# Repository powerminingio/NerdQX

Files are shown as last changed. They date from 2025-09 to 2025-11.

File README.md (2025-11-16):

NerdQX
<sup>Revision 1.0</sup>

> The standard and spearhead of current multi-ASIC home miners based on open hardware.

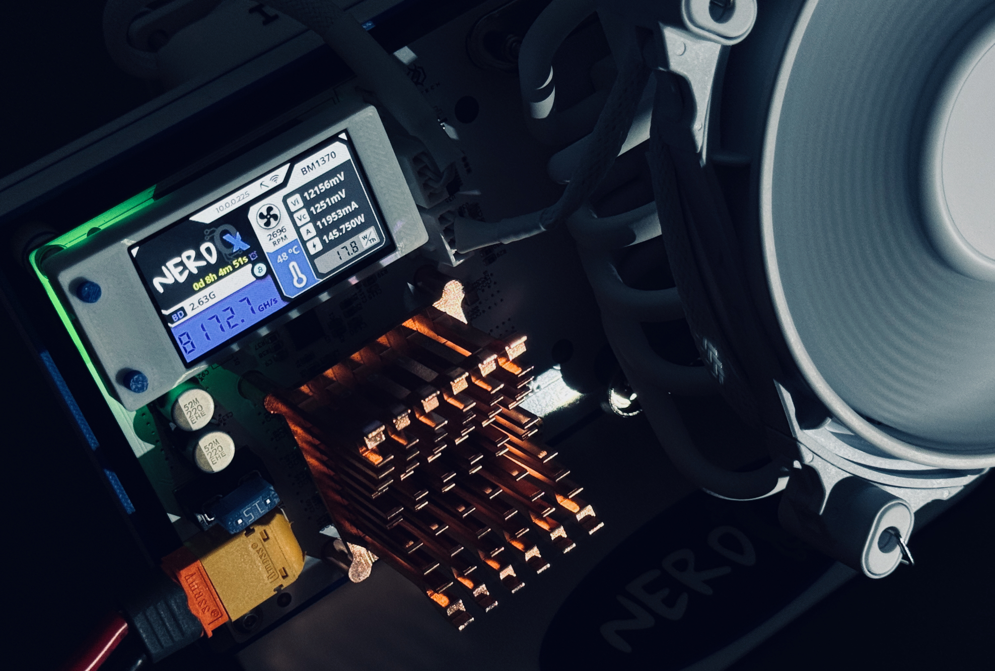
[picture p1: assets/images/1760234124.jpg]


## About

**NerdQX** is a new development based on [NerdQaxe++](https://github.com/shufps/qaxe). NerdQX also has four BM1370 ASIC
chips, a different PCB geometry, and significantly improved and simplified safety mechanisms. 

The NerdQX was developed as the world's first multi-ASIC home miner for overclocking, which also enables extremely 
efficient mining. Furthermore, the NerdQX can measure the temperature of all four ASICs separately and directly, in 
addition to the existing and somewhat less accurate variant. 

NerdQX offers full compatibility with the [ESP Miner NerdQAxe+](https://github.com/shufps/ESP-Miner-NerdQAxePlus) 
firmware, which has been specially enhanced for the NerdQX. This means you get the benefits of ongoing support and 
further development on an open source basis. 

Many small and large improvements make the NerdQX the new standard for multi-ASIC home miners based on open hardware.

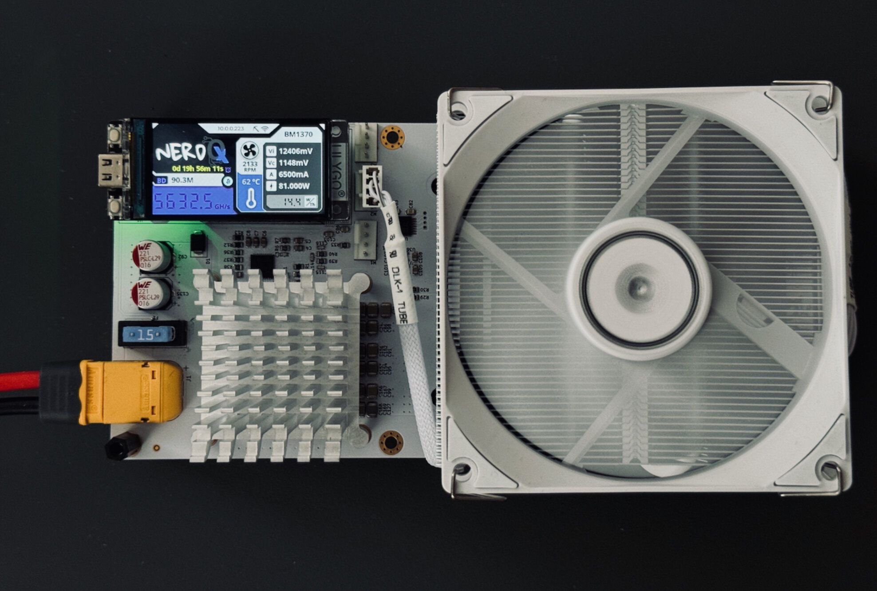
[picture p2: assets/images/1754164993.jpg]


## Highlights

### Four ASIC BM1370 processors with clock speeds up to 1000 MHz
> Unique in open-source home mining worldwide – ready for performance or economy mode.

### New PCB design with significantly increased copper and optimized conductor tracks
> The entire layout of the NerdQX has been redesigned electrically and thermally. The use of a significantly higher 
  copper ratio in the conductor tracks significantly improves the current carrying capacity of the board – even 
  under permanently high ASIC loads. The wider spacing and targeted routing ensure stable power supply, reduced heat 
  loss, and more even temperature distribution, while at the same time greatly improving efficiency.

### Dedicated cooling of the VREGs with custom-made heat sinks
> Unlike previous DIY miners, where voltage regulators often remain completely uncooled, NerdQX sets a new standard 
  here: The VREGs have been mechanically offset to enable the best possible airflow and heat dissipation. 
  In combination with a customized, thermally adapted heat sink, the resulting power loss is efficiently dissipated – 
  a concept that has previously only been used in industrial mining rigs. This measure not only extends the service 
  life of the components, but also allows safe overclocking without the risk of thermal instability in the power range 
  for the first time.
  
> **NOTE:** This heatsink is available from [Ix Tech](https://ixtech.xyz) not DigiKey.

### XT60 power connector
> Industry standard: extremely low contact resistance, high current carrying capacity, and reliable contact - even 
  in mobile or vibration-prone setups.

### Mini automotive fuse, set to the NerdQX power rating of 15 amps
> Robust, cost-effective, and easy to replace – provides additional protection against short circuits or overcurrent 
  without the need for complicated safety mechanisms, while allowing for simple visual checks of functionality.

### 4-pin PWM connector for up to three fans or AiO cooling
> Modular, efficient, prepared for quiet or aggressive cooling strategies.

### Rounded PCB corners for better protection and a high-quality overall impression
> A detail that makes safety and manufacturing quality visible.

### Proprietary open-source firmware
> The NerdQX firmware is based on the established open source NerdQaxe++ firmware, but has been specifically 
  enhanced for the new design and architecture of the NerdQX. These adjustments allow the NerdQX to be precisely 
  controlled in the range from underclocking to high-performance operation without compromising security or 
  transparency.

### Significantly improved sensor technology for temperature monitoring of all four ASICs
> Precise temperature measurement allows perfect control over thermal development during cooling. In addition to the 
  not entirely accurate temperature measurement of the ASIC, the NerdQX allows direct measurement and output of the 
  current temperature per ASIC processor for the first time.

## Collaboration

The NerdQX project was developed by an international team of enthusiasts. 

| Ix Tech | PlebBase | phil31 | shufps |
|---|---|---|---|
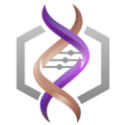
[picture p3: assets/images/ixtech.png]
Ix Tech (https://ixtech.xyz)
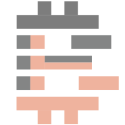
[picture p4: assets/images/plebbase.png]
PlebBase (https://plebbase.com)
|   |  | (https://github.com/phil31) | (https://github.com/shufps) |
| (https://x.com/IxTechCrypto) | (https://x.com/trendkraft) | | (https://x.com/Pmaxsd) |
 
> Special thanks go to shufps, who developed the NerdQaxe and the corresponding firmware; without him, much of this would
  not have been possible. Thanks also go to the many other talented developers who have been involved in the Nerd* 
  projects so far.

## Development

The further development of the NerdQX is being actively pursued in order to develop additional ideas and features with
the goal of creating the perfect multi-ASIC home miner that sets new standards.

## Table of Content

* [NerdQX original sources](assets/ORIGINAL_SOURCES.md)
* [NerdQX review on PlebBase](https://plebbase.com/development/all-eyez-nerdqx)
* [Official firmware](https://github.com/shufps/ESP-Miner-NerdQAxePlus)
* [Changelog](assets/CHANGELOG.md) of the project.

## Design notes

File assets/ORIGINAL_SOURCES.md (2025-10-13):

# 🛡️ NerdQX ORIGINAL

NerdQX Logo

The **NerdQX project** was created by an international team of enthusiasts and is released as an **open-source initiative**.

## Collaboration 🤝

- The project may only be built and distributed under **open-source principles**.
- Any distribution or resale must always link back to the **official source repository**.
- Unauthorized or closed-source derivatives are not permitted.
- If you would like to be listed as an original source or reseller, please **[contact the project team](https://plebbase.com/nerdqx-core-team) directly**.

We kindly encourage new manufacturers or sellers to also **support the team’s ongoing efforts**. The development of 
NerdQX has required significant time and resources, and the project continues to be actively maintained and improved.
Voluntary contributions or forms of appreciation help ensure that the developers can continue to build and enhance the 
project — and any support provided will be shared directly among the core team members.

---

## Important Notice ⚠️
This is the **only official list** of legitimate sources for the NerdQX.
- Only the links listed here are **trusted and verified**.
- Any other websites, shops, or offers are **not authorized**.
- Similarly, shops that are not on this list **do not support** the project and pose an ethical problem.
- The core team does **not provide** support for non-ORIGINAL NerdQX.

👉 Always purchase through the original sources listed below.

---

## Original sources

| Provider / Shop | Website | Region | Shipping | Contact |
|---|---|---|---|---|
| **Ix Tech** | [ixtech.xyz](https://ixtech.xyz/) | USA  | Worldwide | support@ixtech.xyz |

---

© 2025 NerdQX Project.

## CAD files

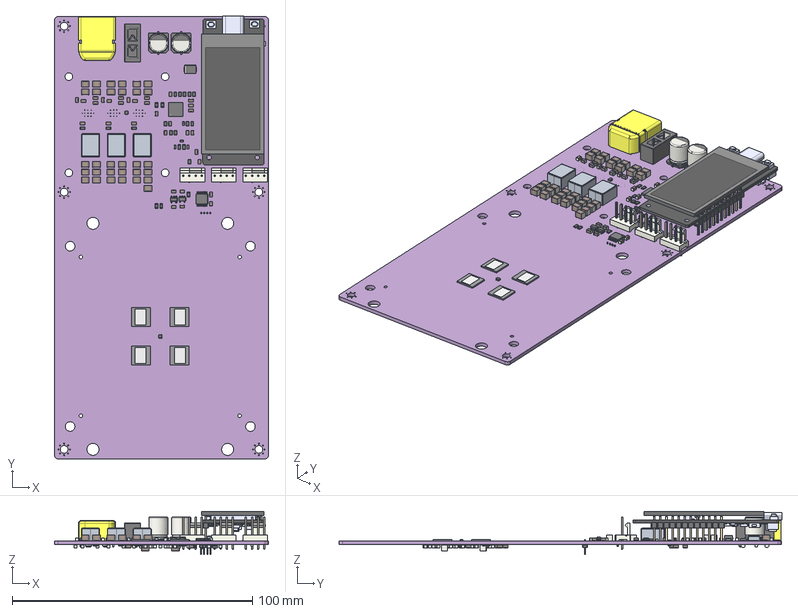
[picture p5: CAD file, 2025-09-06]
assets/3d model/NerdQX.step
89.0 x 184.2 x 17.9 mm
C_1210_3225Metric x 36
R_0805_2012Metric x 43
C_0805_2012Metric x 100
SOT-563 x 2
11150900A x 6
53134900A x 3
Label for FP1006V2-R x 3
CP_Elec_8x10 x 2
C_0603_1608Metric x 4
QFN-40-1EP_6x6mm_P0.5mm
FanPinHeader_1x04_P2.54mm_Vertical x 3
MainBoard_3D
Ecran
1_Male_Pin_2.54_mm x 24
D_SMB
TSSOP-14_4.4x5mm_P0.65mm
SOT-23-5 x 2
Fuseholder_Blade_Mini_Keystone_3568
D_SOD-128
XT60PW-M--3DModel-STEP-269445
SOT-23-6
NerdQX 1.88.1
VSSOP-8_2.3x2mm_P0.5mm
MSOP-10_3x3mm_P0.5mm
D_SOD-123
PinHeader_1x04_P1.27mm_Vertical
WSON-8-1EP_2x2mm_P0.5mm_EP0.9x1.6mm
Nerd QX_PCB

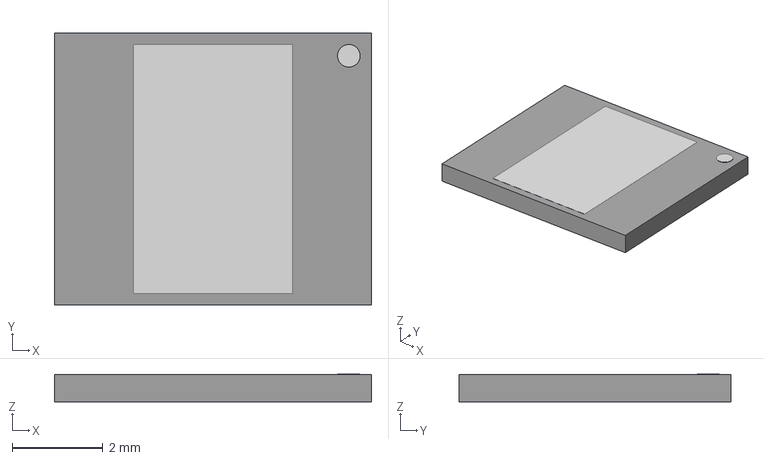
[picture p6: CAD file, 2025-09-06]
scheme/3d/bm1366.step
7.00 x 6.00 x 0.61 mm

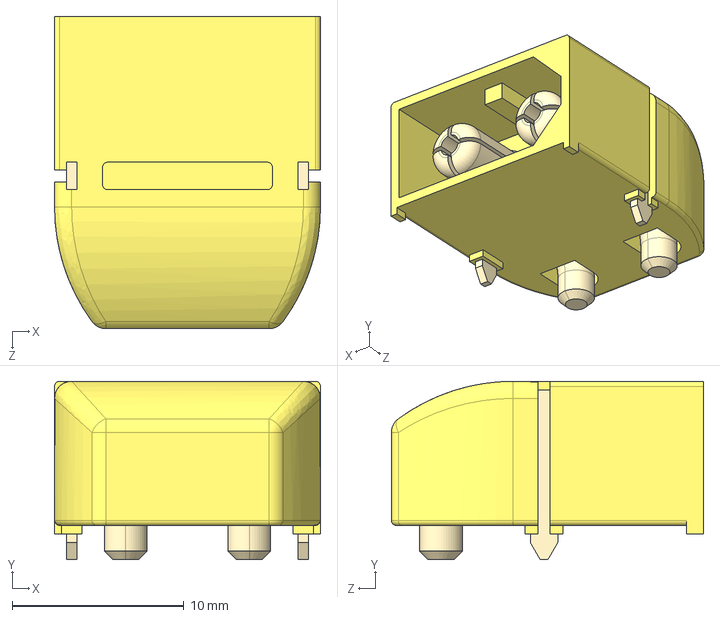
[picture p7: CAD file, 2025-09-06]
scheme/3d/XT60PW MALE.STEP
15.5 x 10.4 x 18.2 mm

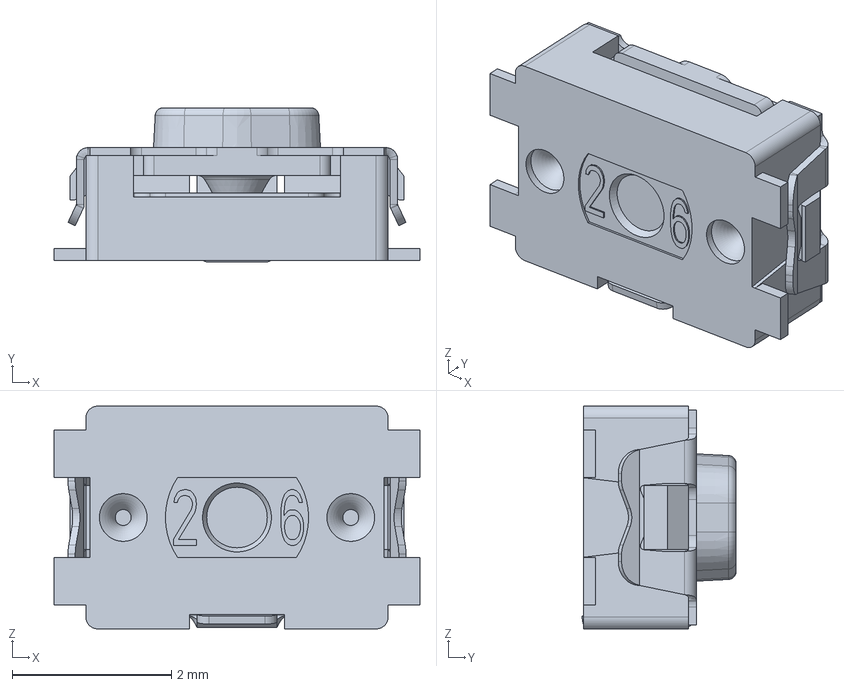
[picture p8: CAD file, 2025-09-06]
scheme/3d/KMR231GLFS.stp
4.60 x 1.94 x 2.80 mm

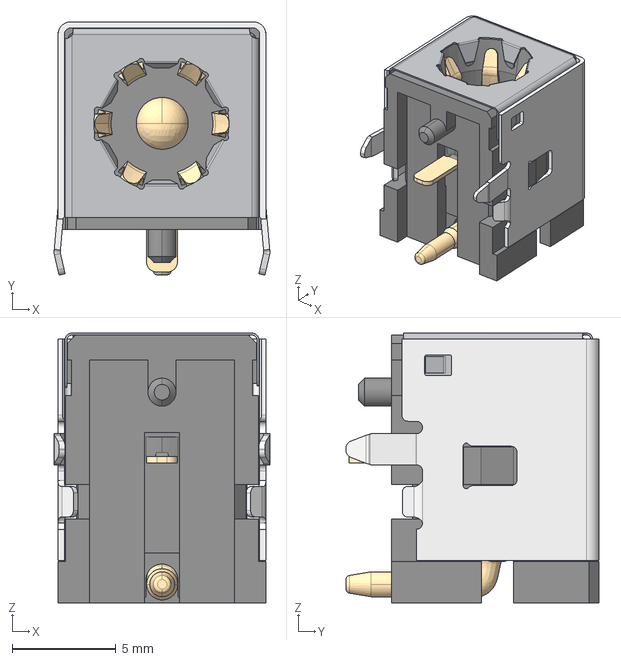
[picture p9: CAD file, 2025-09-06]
scheme/3d/DCJ250-20-B-XX-X_REVA1.step
10.4 x 12.2 x 13.0 mm

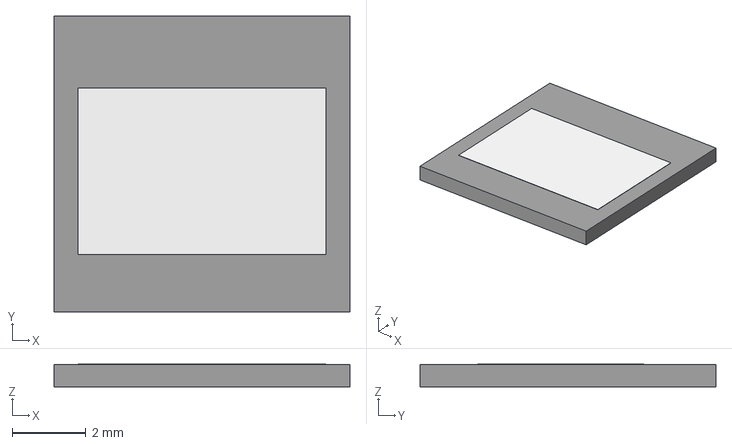
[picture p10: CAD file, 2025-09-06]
scheme/3d/bm1370.step
8.00 x 8.00 x 0.61 mm

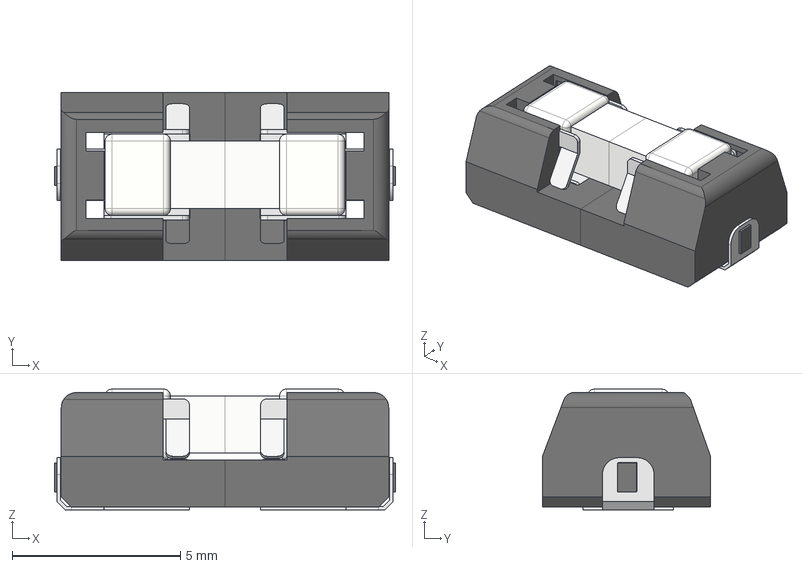
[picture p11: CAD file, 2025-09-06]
scheme/3d/Littelfuse 0154.500DRT without value_black v2.step
10.1 x 5.00 x 3.59 mm
Komponente1
Komponente2
Komponente3
Komponente4

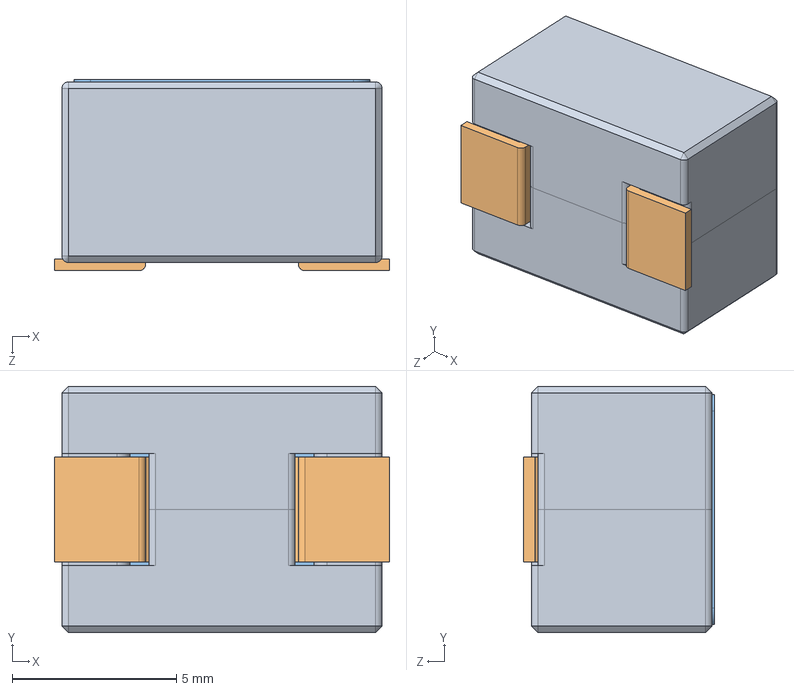
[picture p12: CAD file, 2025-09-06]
scheme/3d/FP1006V2-R.STEP
10.2 x 7.50 x 5.83 mm
11150900A x 2
53134900A
Label for FP1006V2-R

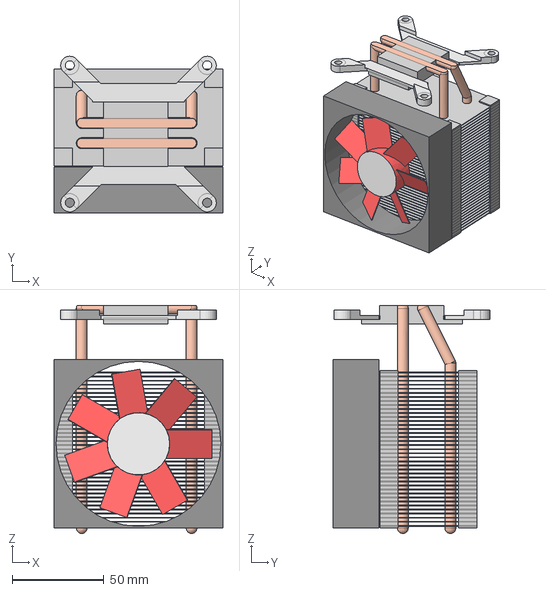
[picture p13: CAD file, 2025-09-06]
scheme/3d/lga115x.step
92.0 x 85.5 x 124.5 mm

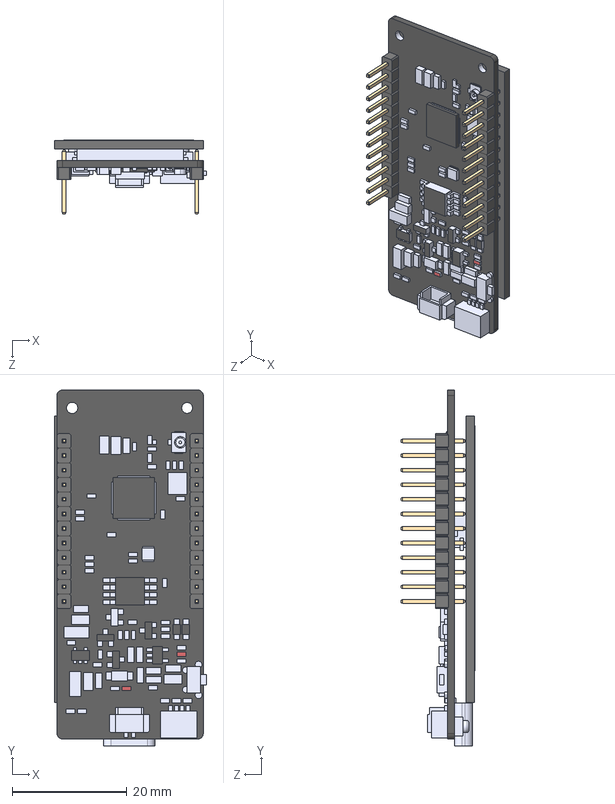
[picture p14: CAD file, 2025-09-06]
scheme/3d/T-Display-S3.STEP
26.5 x 62.0 x 12.9 mm
MainBoard_3D
Ecran
1_Male_Pin_2.54_mm x 24

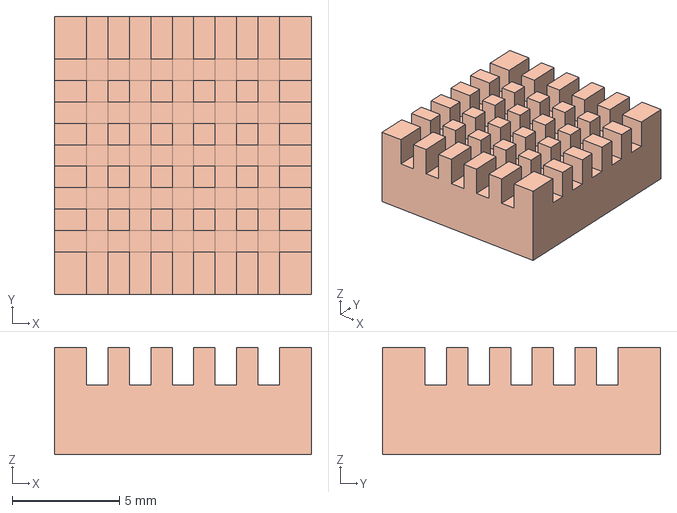
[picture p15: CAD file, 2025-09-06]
scheme/3d/heatsink-13x12x5.step
12.0 x 13.0 x 5.00 mm

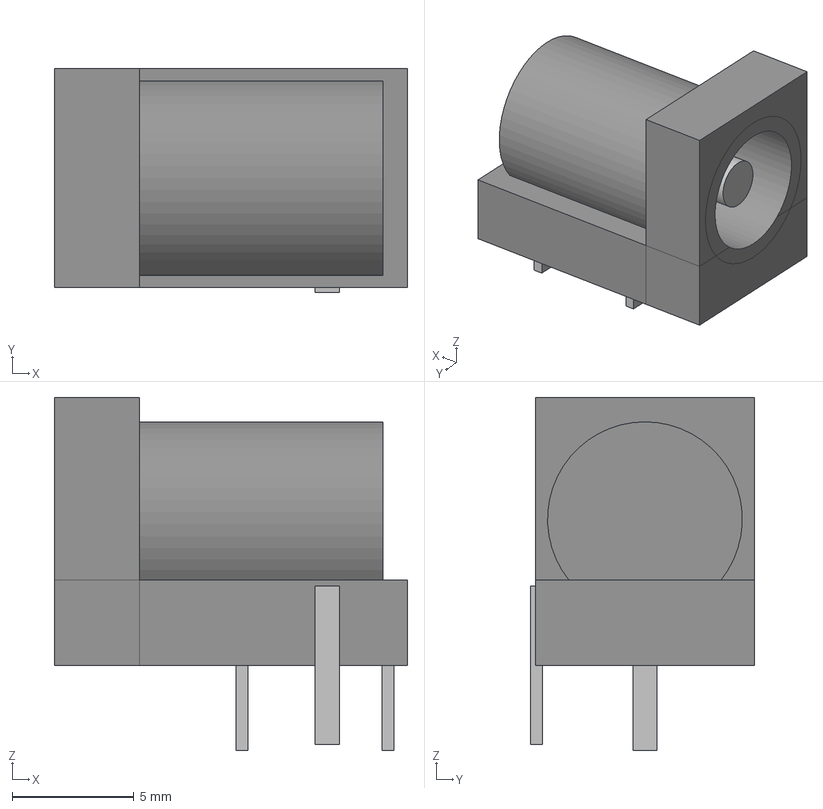
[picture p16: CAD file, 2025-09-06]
scheme/3d/barrel-jack.step
14.5 x 9.20 x 14.5 mm

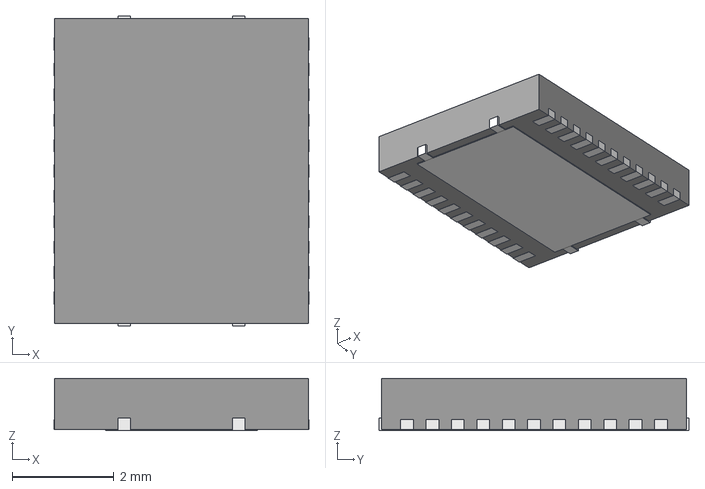
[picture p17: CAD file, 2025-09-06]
scheme/3d/csg95472.step
5.02 x 6.10 x 1.02 mm

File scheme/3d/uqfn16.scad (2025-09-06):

color("#505050") cube([1.8,2.6,0.5]);

translate([0.15, 2.6/2, 0.13/2-0.01]) {
    for (i=[-0.6:0.4:0.6]) {
        translate([0, i,0]) color("lightgray") cube([0.4,0.2,0.13], center=true);
    }
}

translate([0.15+1.5, 2.6/2, 0.13/2-0.01]) {
    for (i=[-0.6:0.4:0.6]) {
        translate([0, i,0]) color("lightgray") cube([0.4,0.2,0.13], center=true);
    }
}


translate([1.8/2,0.16, 0.13/2-0.01]) {
    for (i=[-0.6:0.4:0.6]) {
        translate([i, 0,0]) color("lightgray") cube([0.2,0.4,0.13], center=true);
    }
}

translate([1.8/2,2.45, 0.13/2-0.01]) {
    for (i=[-0.6:0.4:0.6]) {
        translate([i, 0,0]) color("lightgray") cube([0.2,0.4,0.13], center=true);
    }
}

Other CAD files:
scheme/3d/bm1370.scad
scheme/3d/csd95472.scad

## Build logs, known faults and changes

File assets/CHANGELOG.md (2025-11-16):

# Changelog for NerdQX project
## Revisions

### 1.0.1
* Capacitors increased to a higher nF rated power
* Updated schematics with correct cap rating
* Gerber list re-exported and verified
* Pick & Place list/configuration exported and verified
* BOM updated according to current schematics

### 1.0
* Horizontal PCB geometry and alignment
* New alignment of voltage regulators
* XT60 power connection
* Increase in trace spacing compliance
* Add fiducials for both sides
* Mounting holes for custom VREG coolers implemented
* Add I2C pull-up
* Temperature diode positioned centrally between ASIC processors
* Tmux implemented for direct ASIC measurement
* Additional 4-pin for fan implemented (M3)
* Blade-type fuse holder supporting up to 30A mini automotive fuse
* Round corners of PCB

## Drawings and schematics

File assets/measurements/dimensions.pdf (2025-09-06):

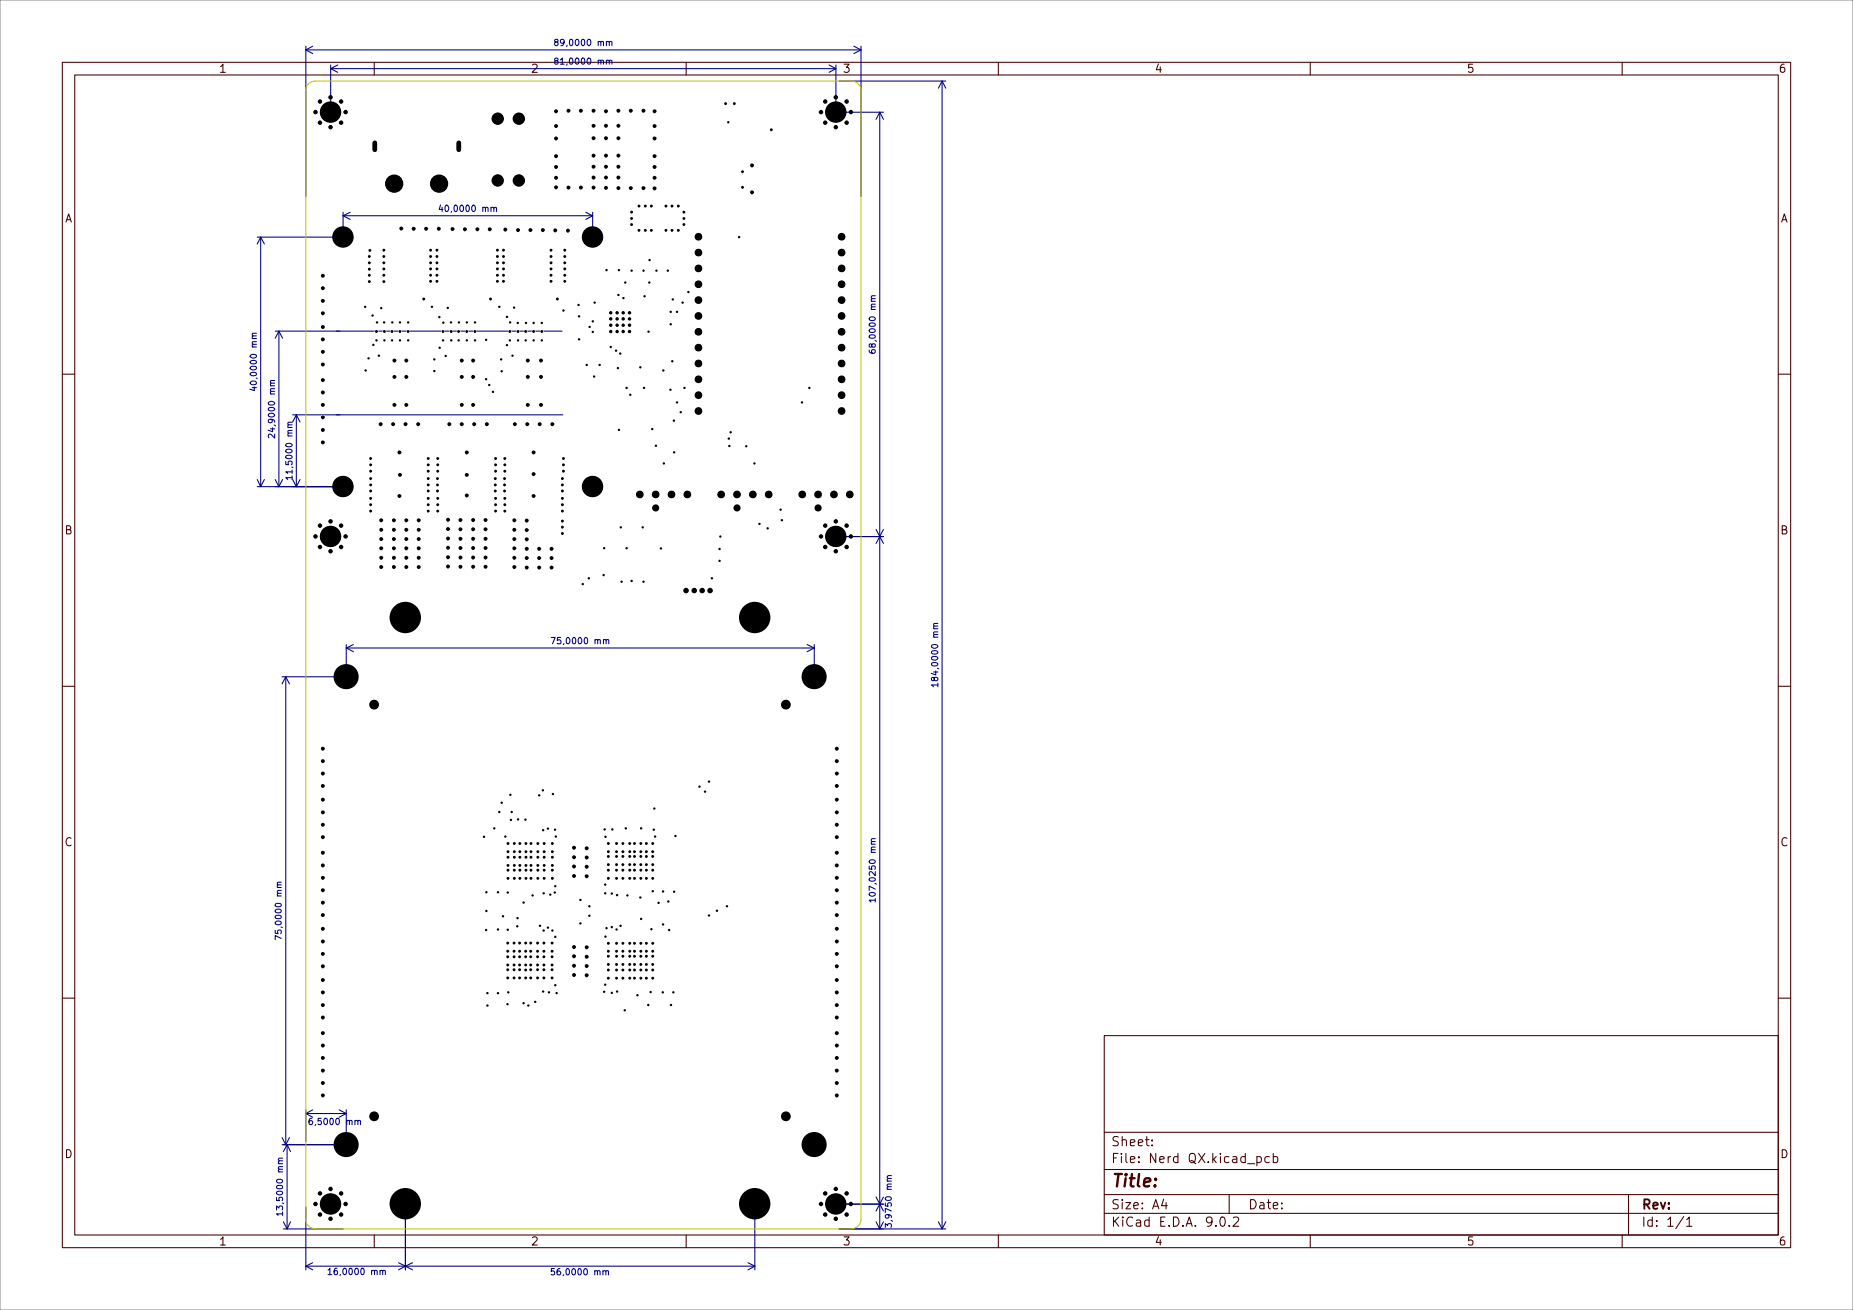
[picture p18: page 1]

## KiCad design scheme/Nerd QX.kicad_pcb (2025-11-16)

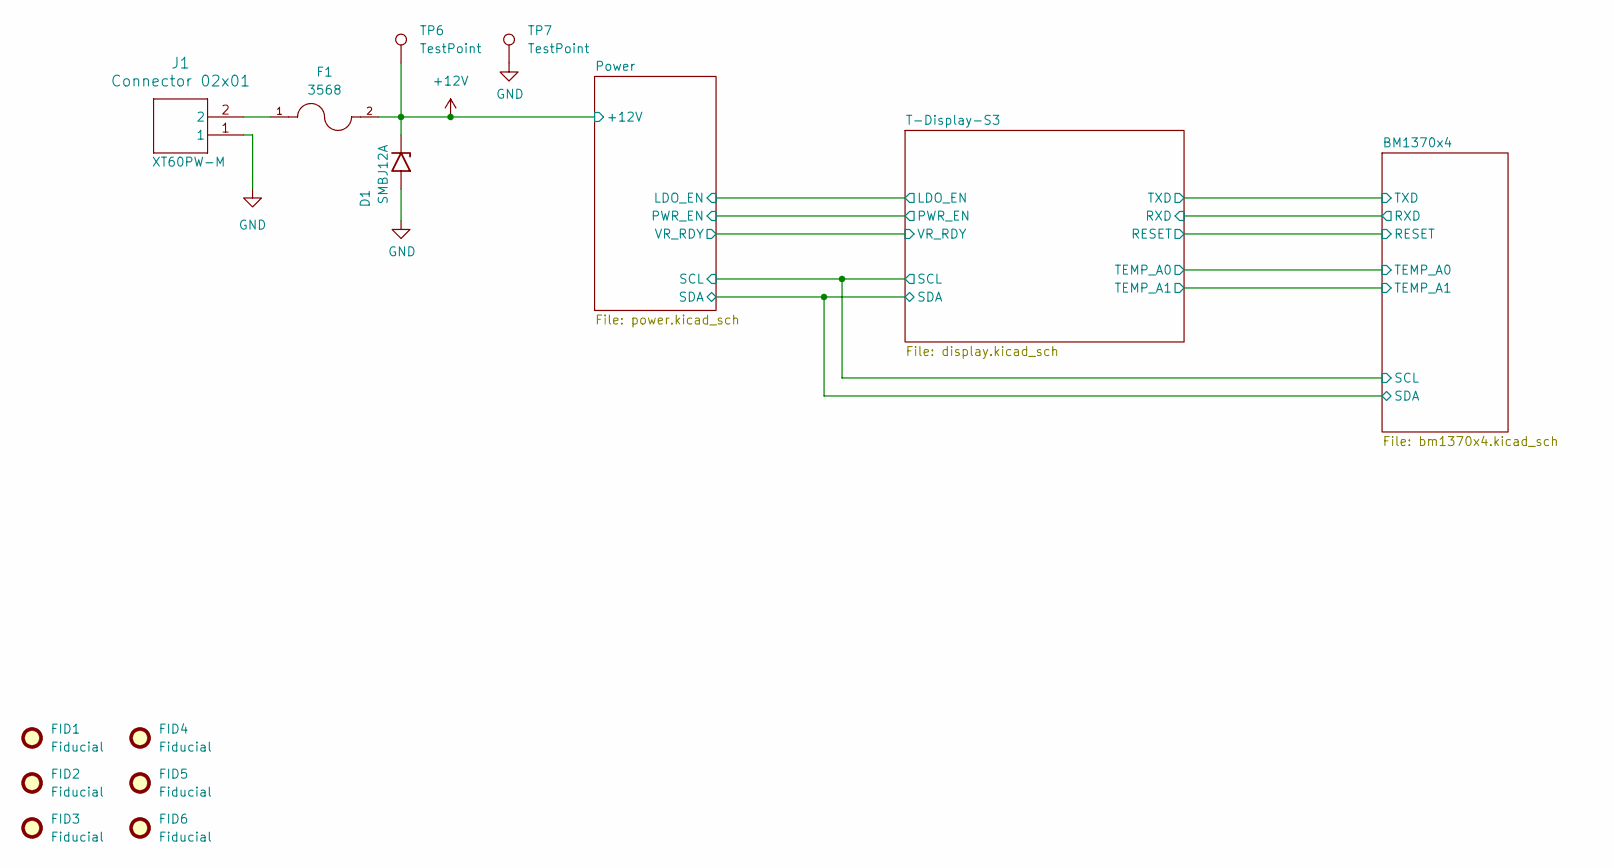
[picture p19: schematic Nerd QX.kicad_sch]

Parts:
D1: SMBJ12A; D_SMB
F1: 3568; Fuseholder_Blade_Mini_Keystone_3568
FID1, FID2, FID3, FID4, FID5, FID6: Fiducial; Fiducial_1mm_Mask3mm
J1: Connector 02x01; AMASS_XT60PW-M_1x02_P7.20mm_Horizontal
TP6, TP7: TestPoint; TestPoint_Pad_D2.0mm

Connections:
+12V: D1.1 (A1), F1.2, TP6.1; also elsewhere on the board
GND: D1.2 (A2), J1.1, TP7.1; also elsewhere on the board
unnamed: F1.1, J1.2

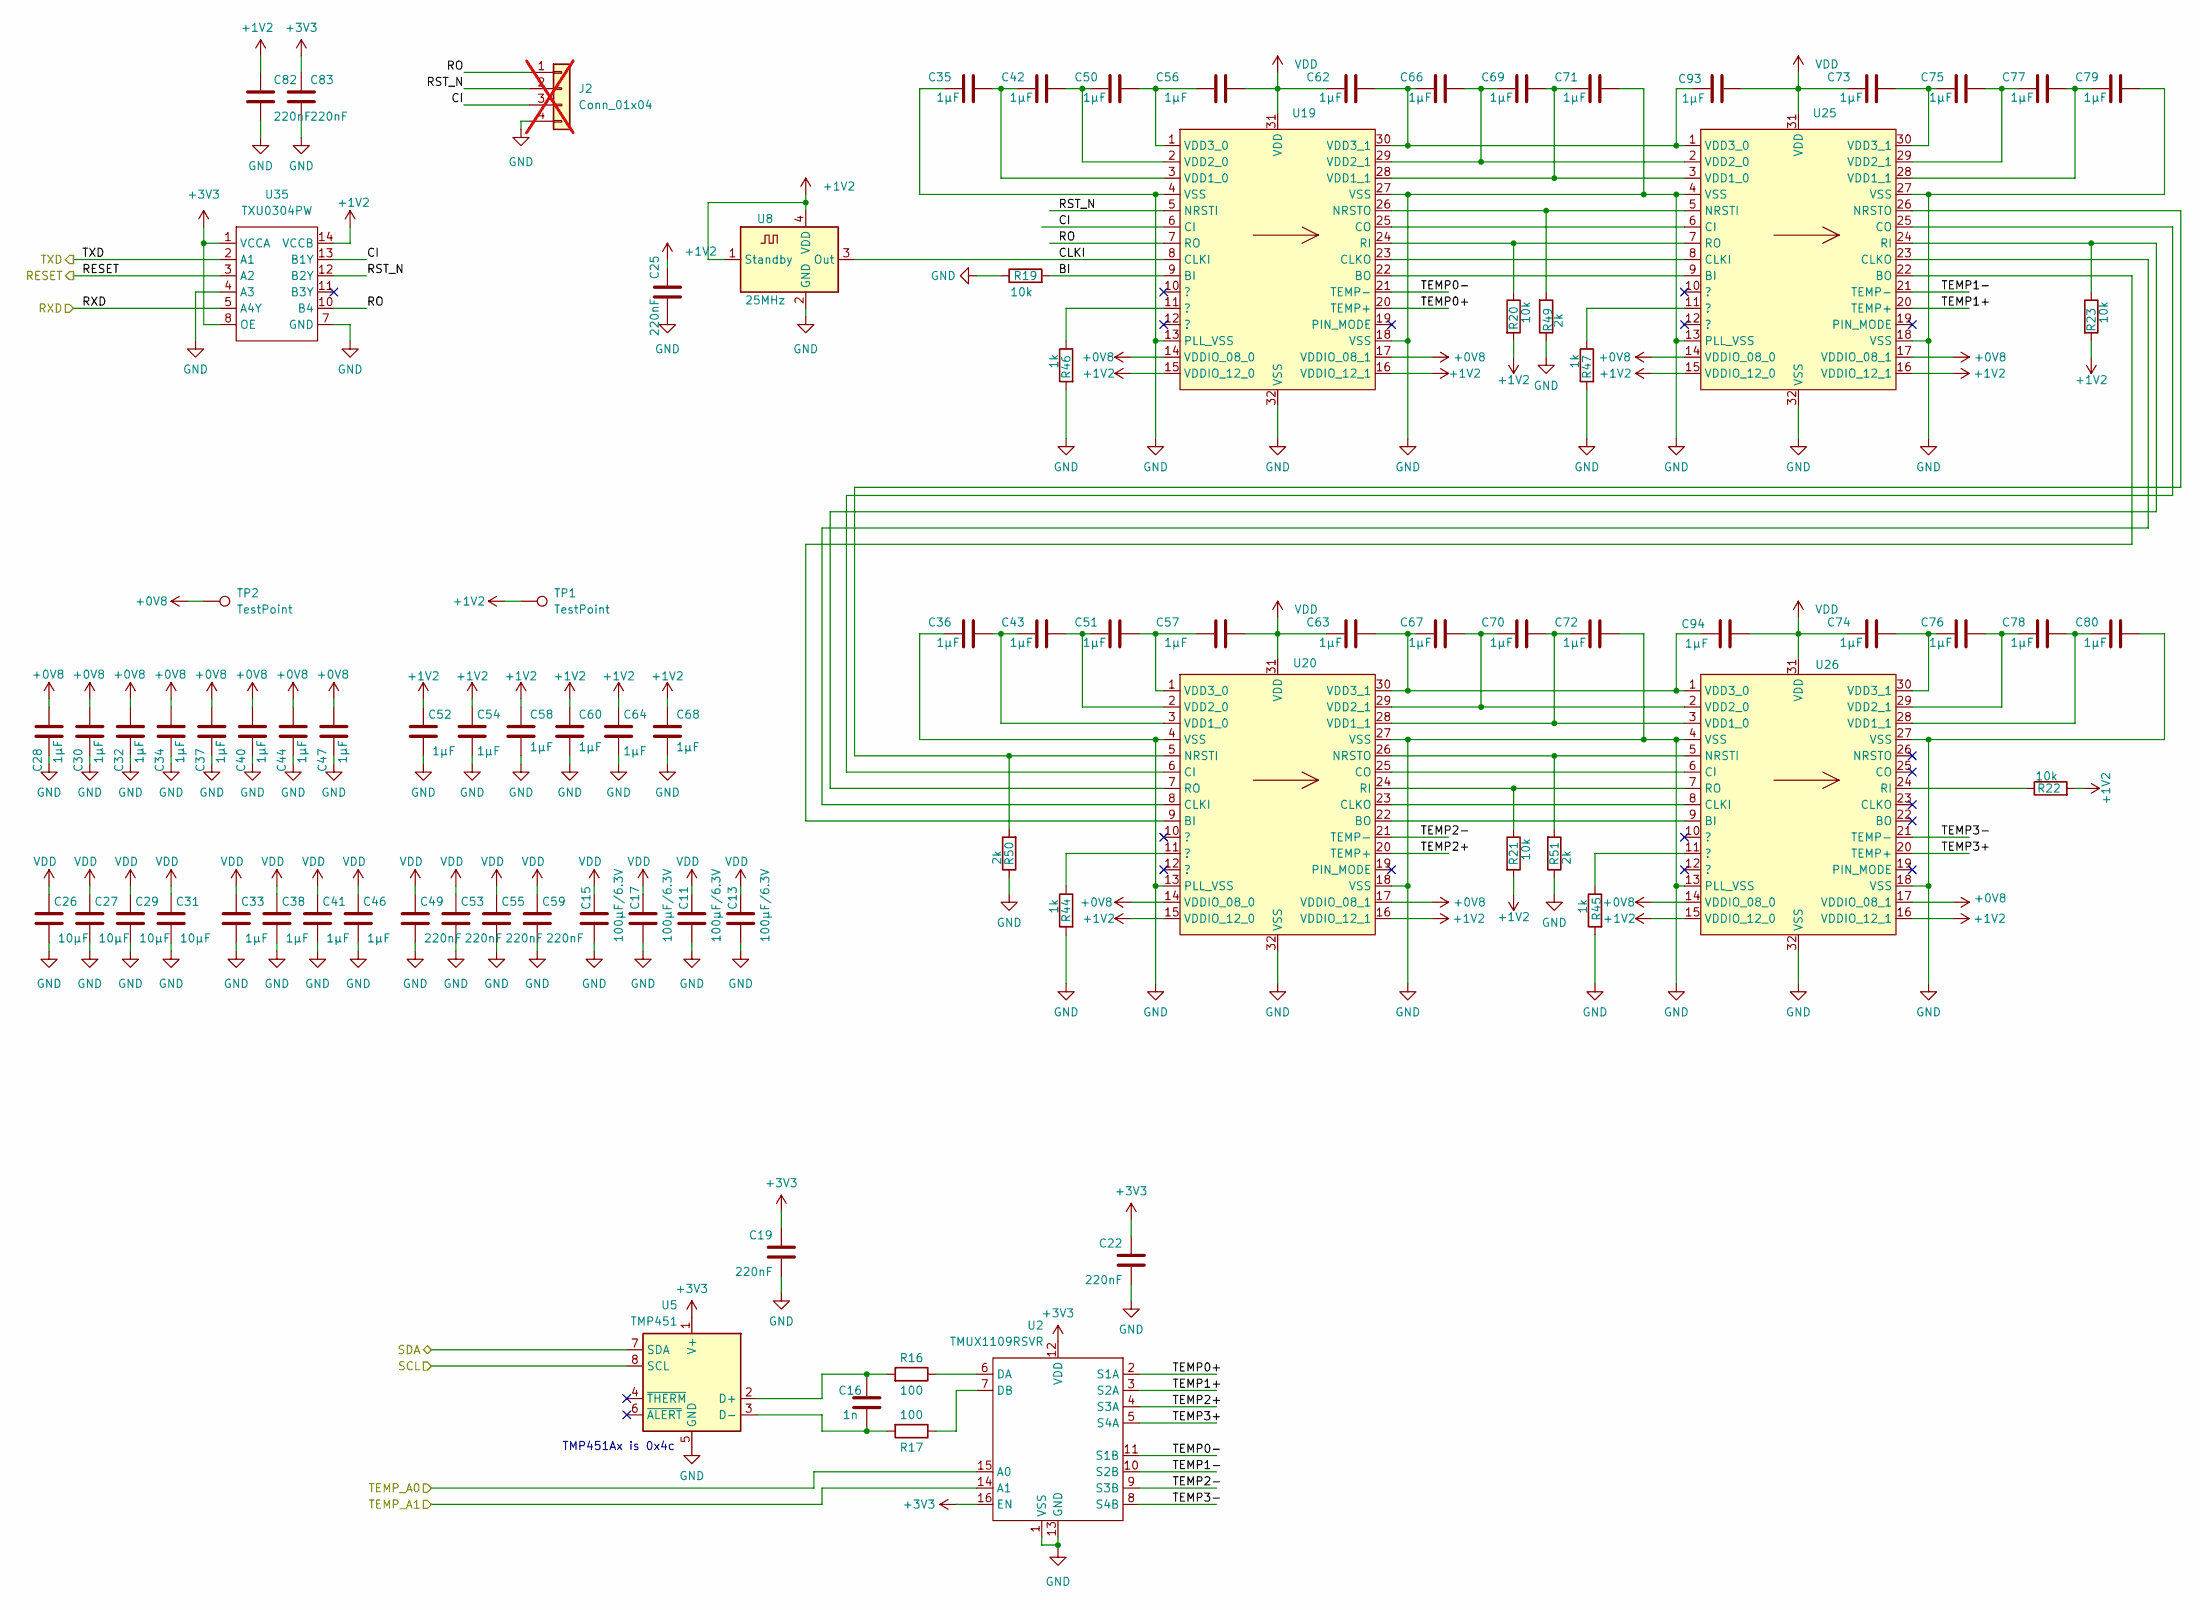
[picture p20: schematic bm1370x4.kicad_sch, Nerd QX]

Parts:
C11, C13, C15, C17: 100µF/6.3V; C_1210_3225Metric
C16: 1n; C_0805_2012Metric
C19, C22, C25, C49, C53, C55, C59, C82, C83: 220nF; C_0805_2012Metric
C26, C27, C29, C31: 10µF; C_0805_2012Metric
C28, C30, C32, C33, C34, C35, C36, C37, C38, C40, C41, C42, C43, C44, C46, C47, C50, C51, C52, C54, C56, C57, C58, C60, C62, C63, C64, C66, C67, C68, C69, C70, C71, C72, C73, C74, C75, C76, C77, C78, C79, C80, C93, C94: 1µF; C_0805_2012Metric
J2: Conn_01x04; PinHeader_1x04_P1.27mm_Vertical; not fitted
R16, R17: 100; R_0805_2012Metric
R19, R20, R21, R22, R23: 10k; R_0805_2012Metric
R44, R45, R46, R47: 1k; R_0805_2012Metric
R49, R50, R51: 2k; R_0805_2012Metric
TP1, TP2: TestPoint; TestPoint_Pad_D2.0mm
U2: TMUX1109RSVR; UQFN-16_1.8x2.6mm_P0.4mm
U5: TMP451; WSON-8-1EP_2x2mm_P0.5mm_EP0.9x1.6mm
U8: 25MHz; Oscillator_SMD_EuroQuartz_XO32-4Pin_3.2x2.5mm
U19, U20, U25, U26: BM1370_mode1; BM1370
U35: TXU0304PW; TSSOP-14_4.4x5mm_P0.65mm

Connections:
+0V8: C28.2, C30.2, C32.2, C34.2, C37.2, C40.2, C44.2, C47.2, TP2.1, U19.14 (VDDIO_08_0), U19.17 (VDDIO_08_1), U20.14 (VDDIO_08_0), U20.17 (VDDIO_08_1), U25.14 (VDDIO_08_0), U25.17 (VDDIO_08_1), U26.14 (VDDIO_08_0), U26.17 (VDDIO_08_1); also elsewhere on the board
+1V2: C25.1, C52.1, C54.1, C58.1, C60.1, C64.1, C68.1, C82.1, R20.2, R21.2, R22.2, R23.2, TP1.1, U8.1 (Standby), U8.4 (VDD), U19.15 (VDDIO_12_0), U19.16 (VDDIO_12_1), U20.15 (VDDIO_12_0), U20.16 (VDDIO_12_1), U25.15 (VDDIO_12_0), U25.16 (VDDIO_12_1), U26.15 (VDDIO_12_0), U26.16 (VDDIO_12_1), U35.14 (VCCB); also elsewhere on the board
+3V3: C19.1, C22.1, C83.1, U2.12 (VDD), U2.16 (EN), U5.1 (V+), U35.1 (VCCA), U35.8 (OE); also elsewhere on the board
/BM1370x4/BI: R19.2, U19.9 (BI)
/BM1370x4/CI: J2.3, U19.6 (CI), U35.13 (B1Y)
/BM1370x4/CLKI: U8.3 (Out), U19.8 (CLKI)
/BM1370x4/RESET: U35.3 (A2); also elsewhere on the board
/BM1370x4/RO: J2.1, U19.7 (RO), U35.10 (B4)
/BM1370x4/RST_N: J2.2, U19.5 (NRSTI), U35.12 (B2Y)
/BM1370x4/RXD: U35.5 (A4Y); also elsewhere on the board
/BM1370x4/TEMP0+: U2.2 (S1A), U19.20 (TEMP+)
/BM1370x4/TEMP0-: U2.11 (S1B), U19.21 (TEMP-)
/BM1370x4/TEMP1+: U2.3 (S2A), U25.20 (TEMP+)
/BM1370x4/TEMP1-: U2.10 (S2B), U25.21 (TEMP-)
/BM1370x4/TEMP2+: U2.4 (S3A), U20.20 (TEMP+)
/BM1370x4/TEMP2-: U2.9 (S3B), U20.21 (TEMP-)
/BM1370x4/TEMP3+: U2.5 (S4A), U26.20 (TEMP+)
/BM1370x4/TEMP3-: U2.8 (S4B), U26.21 (TEMP-)
/BM1370x4/TEMP_A0: U2.15 (A0); also elsewhere on the board
/BM1370x4/TEMP_A1: U2.14 (A1); also elsewhere on the board
/BM1370x4/TXD: U35.2 (A1); also elsewhere on the board
/T-Display-S3/SCL: U5.8 (SCL); also elsewhere on the board
/T-Display-S3/SDA: U5.7 (SDA); also elsewhere on the board
GND: C11.2, C13.2, C15.2, C17.2, C19.2, C22.2, C25.2, C26.2, C27.2, C28.1, C29.2, C30.1, C31.2, C32.1, C33.2, C34.1, C35.1, C36.1, C37.1, C38.2, C40.1, C41.2, C44.1, C46.2, C47.1, C49.2, C52.2, C53.2, C54.2, C55.2, C58.2, C59.2, C60.2, C64.2, C68.2, C71.2, C72.2, C79.2, C80.2, C82.2, C83.2, J2.4, R19.1, R44.2, R45.2, R46.2, R47.2, R49.1, R50.1, R51.1, U2.1 (VSS), U2.13 (GND), U5.5 (GND), U8.2 (GND), U19.4 (VSS), U19.13 (PLL_VSS), U19.18 (VSS), U19.27 (VSS), U19.32 (VSS), U20.4 (VSS), U20.13 (PLL_VSS), U20.18 (VSS), U20.27 (VSS), U20.32 (VSS), U25.4 (VSS), U25.13 (PLL_VSS), U25.18 (VSS), U25.27 (VSS), U25.32 (VSS), U26.4 (VSS), U26.13 (PLL_VSS), U26.18 (VSS), U26.27 (VSS), U26.32 (VSS), U35.4 (A3), U35.7 (GND); also elsewhere on the board
unnamed: R44.1, U20.11 (?)
unnamed: R45.1, U26.11 (?)
unnamed: R46.1, U19.11 (?)
unnamed: R47.1, U25.11 (?)
unnamed: R16.1, U2.6 (DA)
unnamed: R17.1, U2.7 (DB)
unnamed: C16.1, R16.2, U5.2 (D+)
unnamed: C16.2, R17.2, U5.3 (D-)
unnamed: U19.22 (BO), U25.9 (BI)
unnamed: U19.23 (CLKO), U25.8 (CLKI)
unnamed: U19.25 (CO), U25.6 (CI)
unnamed: R49.2, U19.26 (NRSTO), U25.5 (NRSTI)
unnamed: R20.1, U19.24 (RI), U25.7 (RO)
unnamed: C35.2, C42.1, U19.3 (VDD1_0)
unnamed: C69.2, C71.1, U19.28 (VDD1_1), U25.3 (VDD1_0)
unnamed: C42.2, C50.1, U19.2 (VDD2_0)
unnamed: C66.2, C69.1, U19.29 (VDD2_1), U25.2 (VDD2_0)
unnamed: C50.2, C56.1, U19.1 (VDD3_0)
unnamed: C62.2, C66.1, C93.1, U19.30 (VDD3_1), U25.1 (VDD3_0)
unnamed: U20.9 (BI), U25.22 (BO)
unnamed: U20.22 (BO), U26.9 (BI)
unnamed: U20.6 (CI), U25.25 (CO)
unnamed: U20.8 (CLKI), U25.23 (CLKO)
unnamed: U20.23 (CLKO), U26.8 (CLKI)
unnamed: U20.25 (CO), U26.6 (CI)
unnamed: R50.2, U20.5 (NRSTI), U25.26 (NRSTO)
unnamed: R51.2, U20.26 (NRSTO), U26.5 (NRSTI)
unnamed: R21.1, U20.24 (RI), U26.7 (RO)
unnamed: R23.1, U20.7 (RO), U25.24 (RI)
unnamed: C36.2, C43.1, U20.3 (VDD1_0)
unnamed: C70.2, C72.1, U20.28 (VDD1_1), U26.3 (VDD1_0)
unnamed: C43.2, C51.1, U20.2 (VDD2_0)
unnamed: C67.2, C70.1, U20.29 (VDD2_1), U26.2 (VDD2_0)
unnamed: C51.2, C57.1, U20.1 (VDD3_0)
unnamed: C63.2, C67.1, C94.1, U20.30 (VDD3_1), U26.1 (VDD3_0)
unnamed: C77.2, C79.1, U25.28 (VDD1_1)
unnamed: C75.2, C77.1, U25.29 (VDD2_1)
unnamed: C73.2, C75.1, U25.30 (VDD3_1)
unnamed: R22.1, U26.24 (RI)
unnamed: C78.2, C80.1, U26.28 (VDD1_1)
unnamed: C76.2, C78.1, U26.29 (VDD2_1)
unnamed: C74.2, C76.1, U26.30 (VDD3_1)
VDD: C11.1, C13.1, C15.1, C17.1, C26.1, C27.1, C29.1, C31.1, C33.1, C38.1, C41.1, C46.1, C49.1, C53.1, C55.1, C56.2, C57.2, C59.1, C62.1, C63.1, C73.1, C74.1, C93.2, C94.2, U19.31 (VDD), U20.31 (VDD), U25.31 (VDD), U26.31 (VDD); also elsewhere on the board

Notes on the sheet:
TMP451Ax is 0x4c

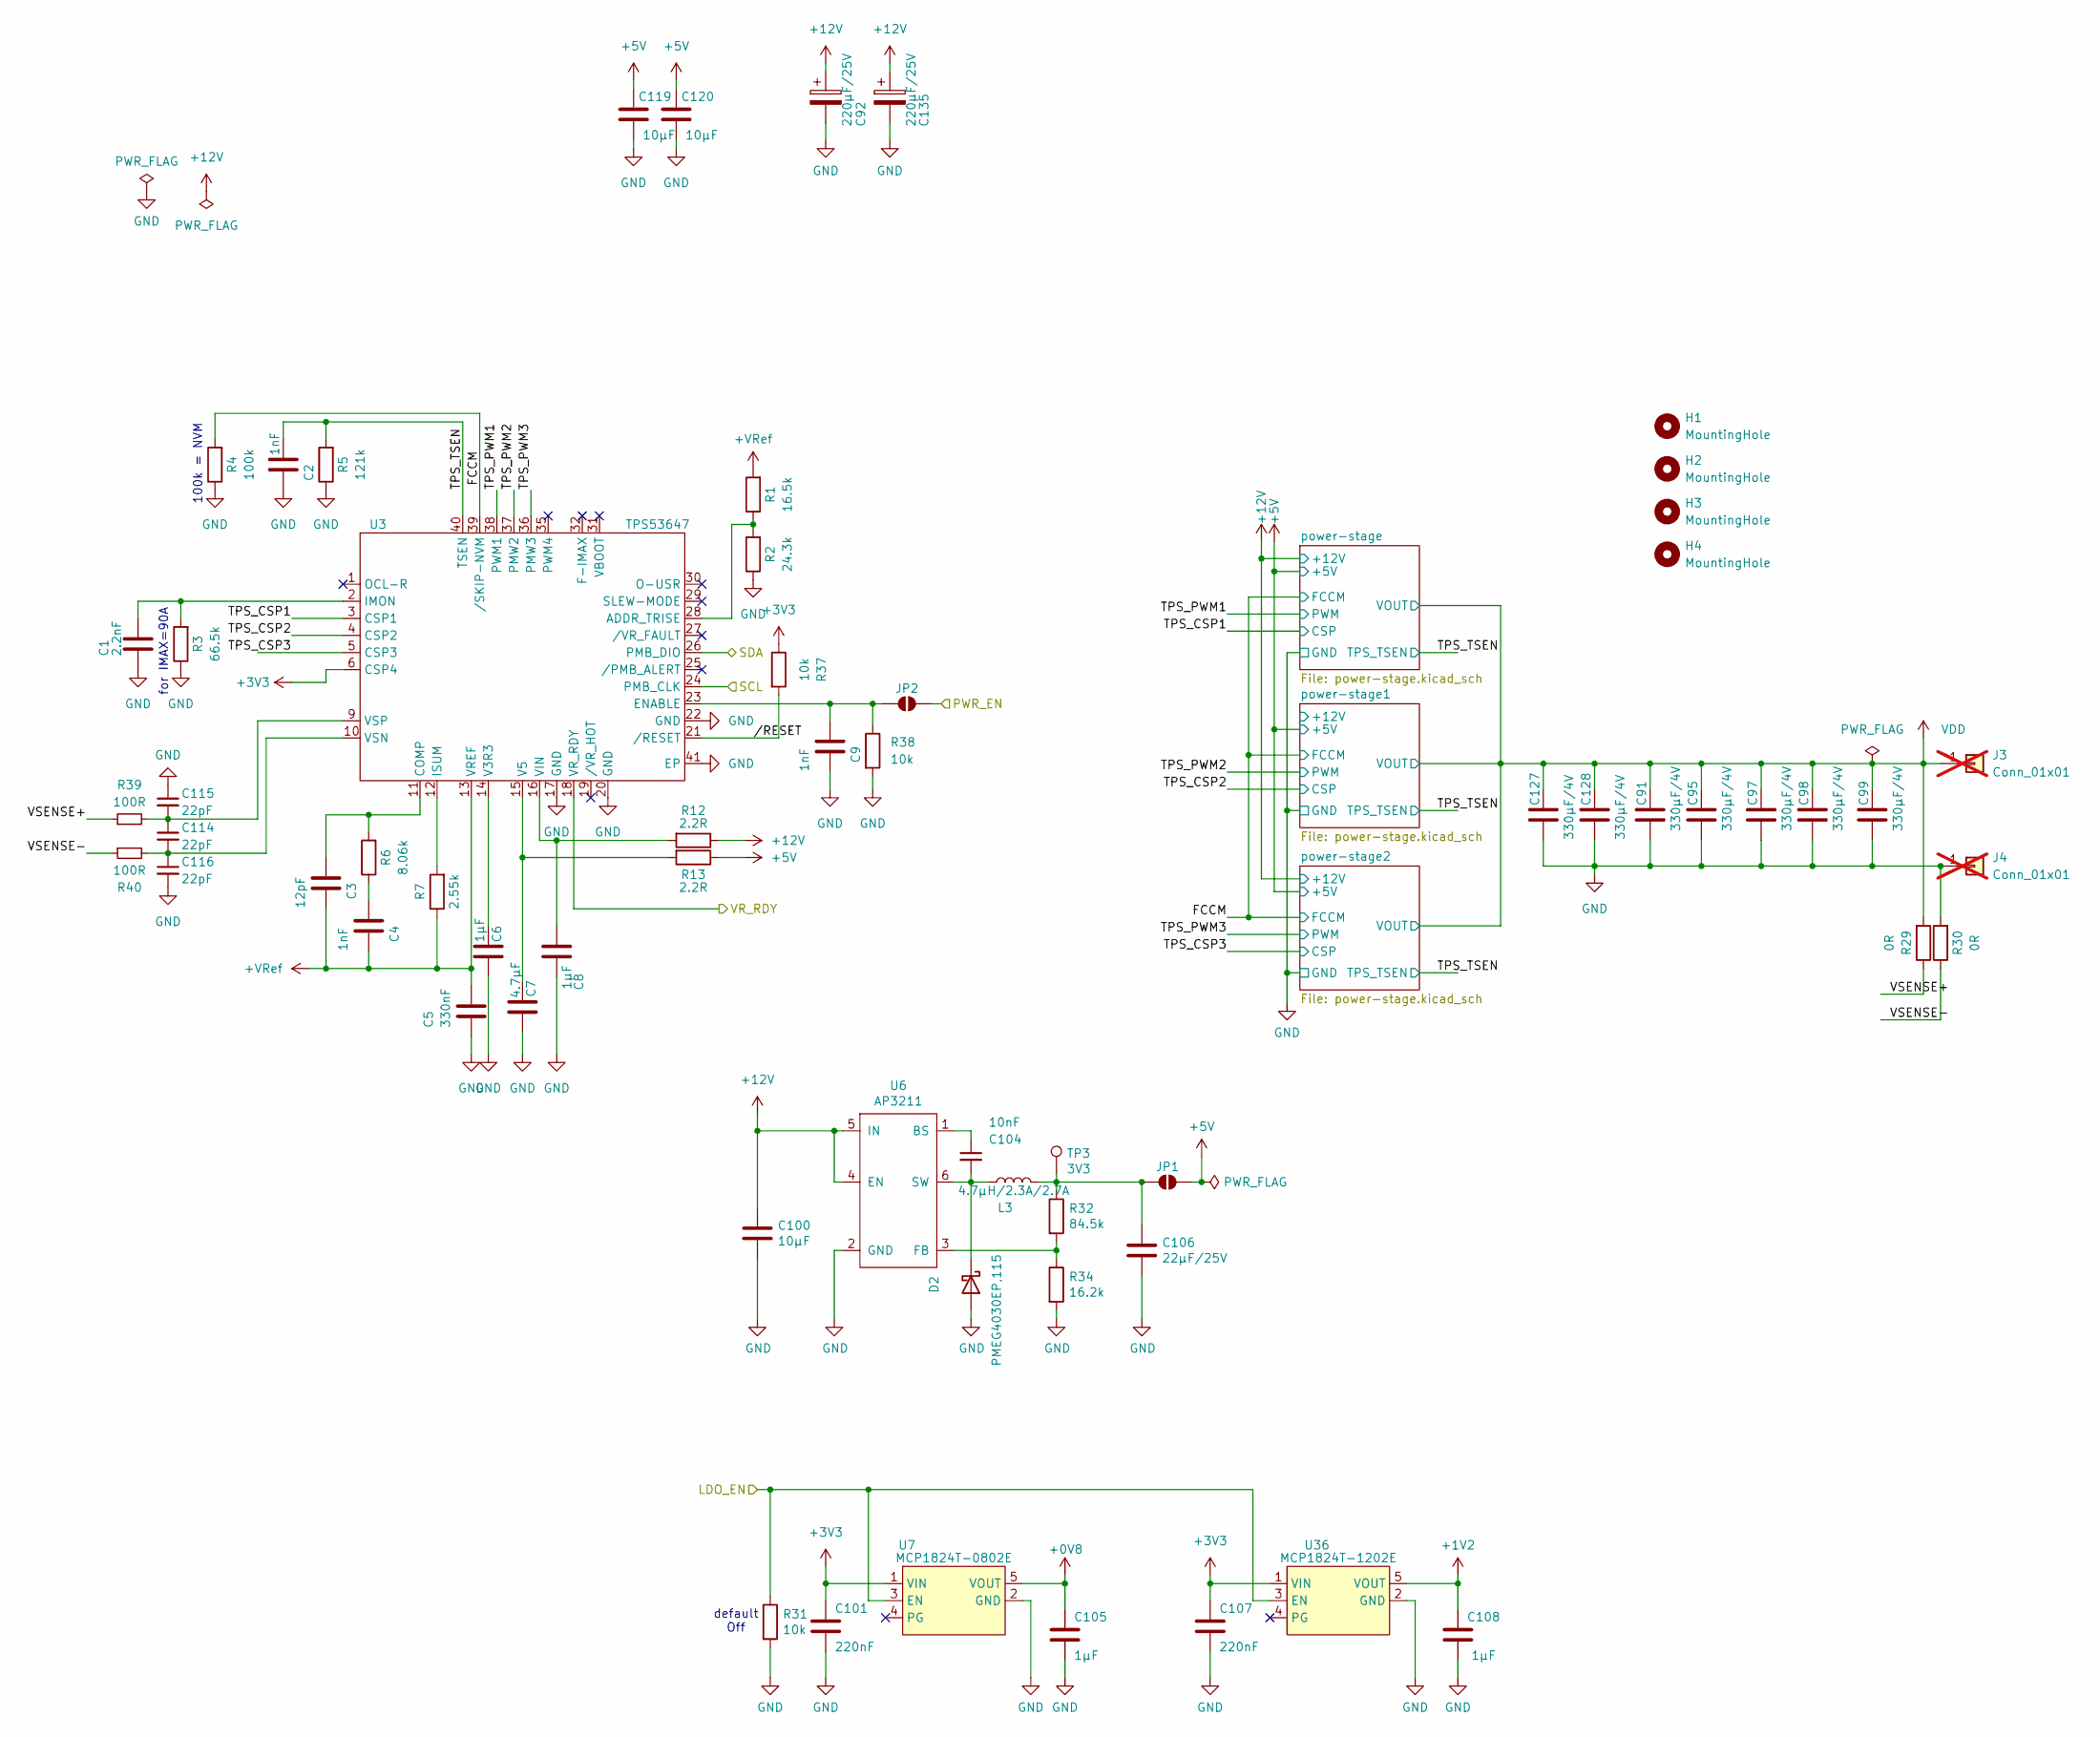
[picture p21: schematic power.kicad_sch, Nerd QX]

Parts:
C1: 2.2nF; C_0805_2012Metric
C2, C4, C9: 1nF; C_0805_2012Metric
C3: 12pF; C_0603_1608Metric
C5: 330nF; C_0805_2012Metric
C6, C8, C105, C108: 1µF; C_0805_2012Metric
C7: 4.7µF; C_0805_2012Metric
C91, C95, C97, C98, C99, C127, C128: 330µF/4V; C_1210_3225Metric
C92, C135: 220µF/25V; CP_Elec_8x10
C100, C119, C120: 10µF; C_0805_2012Metric
C101, C107: 220nF; C_0805_2012Metric
C104: 10nF; C_0805_2012Metric
C106: 22µF/25V; C_1210_3225Metric
C114, C115, C116: 22pF; C_0603_1608Metric
D2: PMEG4030EP,115; D_SOD-128
H1, H2, H3, H4: MountingHole; MountingHole_3.2mm_M3_DIN965_Pad_TopBottom
J3, J4: Conn_01x01; Wuerth_REDCUBE-THR_WP-THRBU_74650194_THR; not fitted
JP1, JP2: SolderJumper_2_Open; SolderJumper-2_P1.3mm_Open_RoundedPad1.0x1.5mm
L3: 4.7µH/2.3A/2.7A; L_Taiyo-Yuden_NR-50xx
R1: 16.5k; R_0805_2012Metric
R2: 24.3k; R_0805_2012Metric
R3: 66.5k; R_0805_2012Metric
R4: 100k; R_0805_2012Metric
R5: 121k; R_0805_2012Metric
R6: 8.06k; R_0805_2012Metric
R7: 2.55k; R_0805_2012Metric
R12, R13: 2.2R; R_0805_2012Metric
R29, R30: 0R; R_0805_2012Metric
R31, R37, R38: 10k; R_0805_2012Metric
R32: 84.5k; R_0805_2012Metric
R34: 16.2k; R_0805_2012Metric
R39, R40: 100R; R_0805_2012Metric
TP3: 3V3; TestPoint_Pad_2.0x2.0mm
U3: TPS53647; Texas_RHA0040B_VQFN-40-1EP_6x6mm_P0.5mm_EP4.15x4.15mm_Therm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
U6: AP3211; SOT-23-6
U7: MCP1824T-0802E; SOT-23-5
U36: MCP1824T-1202E; SOT-23-5

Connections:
+0V8: C105.1, U7.5 (VOUT); also elsewhere on the board
+1V2: C108.1, U36.5 (VOUT); also elsewhere on the board
+3V3: C101.1, C107.1, R37.1, U3.6 (CSP4), U7.1 (VIN), U36.1 (VIN); also elsewhere on the board
+5V: C119.1, C120.1, JP1.2 (B), R13.1; also elsewhere on the board
+12V: C92.1, C100.1, C135.1, R12.1, U6.4 (EN), U6.5 (IN); also elsewhere on the board
+VRef: C3.2, C4.2, C5.1, R1.2, R7.1, U3.13 (VREF); also elsewhere on the board
/Power/FCCM: R4.2, U3.39 (/SKIP-NVM); also elsewhere on the board
/Power/LDO_EN: R31.1, U7.3 (EN), U36.3 (EN); also elsewhere on the board
/Power/PWR_EN: JP2.2 (B); also elsewhere on the board
/Power/TPS_CSP1: U3.3 (CSP1); also elsewhere on the board
/Power/TPS_CSP2: U3.4 (CSP2); also elsewhere on the board
/Power/TPS_CSP3: U3.5 (CSP3); also elsewhere on the board
/Power/TPS_PWM1: U3.38 (PWM1); also elsewhere on the board
/Power/TPS_PWM2: U3.37 (PMW2); also elsewhere on the board
/Power/TPS_PWM3: U3.36 (PMW3); also elsewhere on the board
/Power/TPS_TSEN: C2.1, R5.2, U3.40 (TSEN); also elsewhere on the board
/Power/VR_RDY: U3.18 (VR_RDY); also elsewhere on the board
/Power/VSENSE+: R29.1, R39.1
/Power/VSENSE-: R30.1, R40.1
/Power//RESET: R37.2, U3.21 (/RESET)
/T-Display-S3/SCL: U3.24 (PMB_CLK); also elsewhere on the board
/T-Display-S3/SDA: U3.26 (PMB_DIO); also elsewhere on the board
GND: C1.2, C2.2, C5.2, C6.2, C7.1, C8.1, C9.2, C91.2, C92.2, C95.2, C97.2, C98.2, C99.2, C100.2, C101.2, C105.2, C106.2, C107.2, C108.2, C115.1, C116.2, C119.2, C120.2, C127.2, C128.2, C135.2, D2.2 (A), J4.1, R2.1, R3.1, R4.1, R5.1, R30.2, R31.2, R34.2, R38.2, U3.17 (GND), U3.20 (GND), U3.22 (GND), U3.41 (EP), U6.2 (GND), U7.2 (GND), U36.2 (GND); also elsewhere on the board
unnamed: C4.1, R6.1
unnamed: C104.2, D2.1 (K), L3.1, U6.6 (SW)
unnamed: C106.1, JP1.1 (A), L3.2, R32.1, TP3.1
unnamed: C9.1, JP2.1 (A), R38.1, U3.23 (ENABLE)
unnamed: R1.1, R2.2, U3.28 (ADDR_TRISE)
unnamed: C3.1, R6.2, U3.11 (COMP)
unnamed: C1.1, R3.2, U3.2 (IMON)
unnamed: R7.2, U3.12 (ISUM)
unnamed: C6.1, U3.14 (V3R3)
unnamed: C7.2, R13.2, U3.15 (V5)
unnamed: C8.2, R12.2, U3.16 (VIN)
unnamed: C114.2, C116.1, R40.2, U3.10 (VSN)
unnamed: C114.1, C115.2, R39.2, U3.9 (VSP)
unnamed: C104.1, U6.1 (BS)
unnamed: R32.2, R34.1, U6.3 (FB)
VDD: C91.1, C95.1, C97.1, C98.1, C99.1, C127.1, C128.1, J3.1, R29.2; also elsewhere on the board

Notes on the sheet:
default Off
for IMAX=90A
100k = NVM

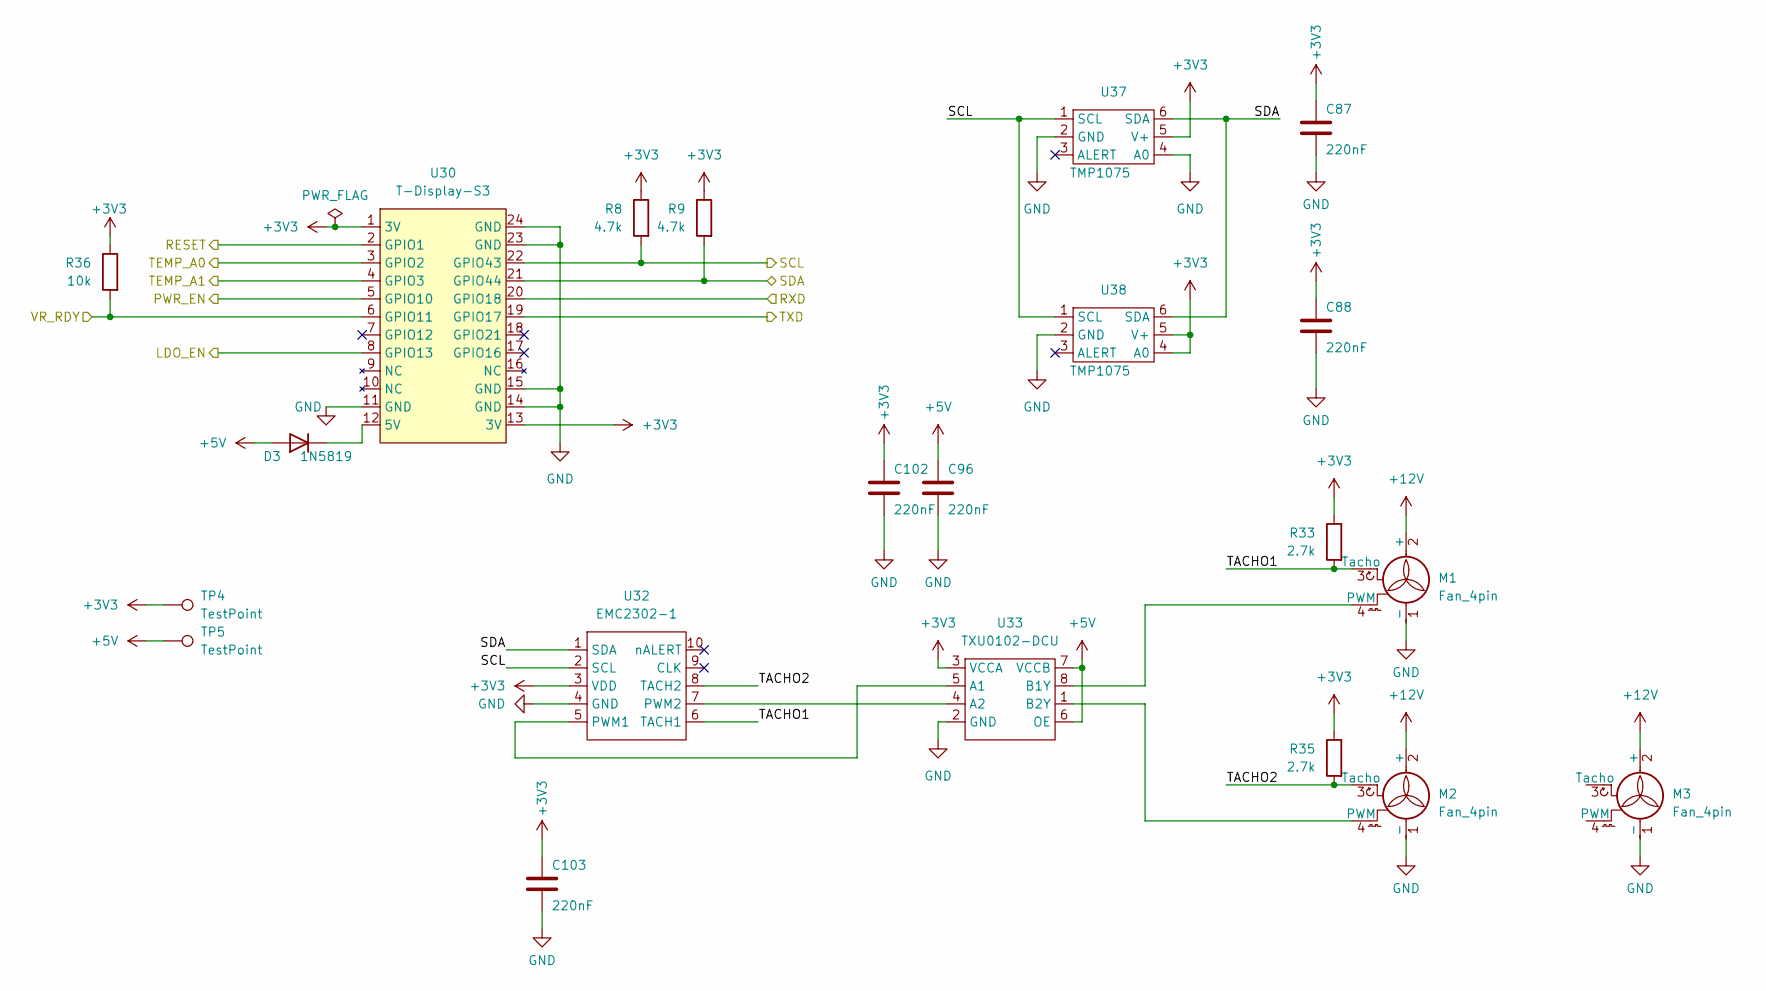
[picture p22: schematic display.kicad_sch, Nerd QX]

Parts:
C87, C88, C96, C102, C103: 220nF; C_0805_2012Metric
D3: 1N5819; D_SOD-123
M1, M2, M3: Fan_4pin; FanPinHeader_1x04_P2.54mm_Vertical
R8, R9: 4.7k; R_0805_2012Metric
R33, R35: 2.7k; R_0805_2012Metric
R36: 10k; R_0805_2012Metric
TP4, TP5: TestPoint; TestPoint_Pad_D2.0mm
U30: T-Display-S3
U32: EMC2302-1; MSOP-10_3x3mm_P0.5mm
U33: TXU0102-DCU; VSSOP-8_2.3x2mm_P0.5mm
U37, U38: TMP1075; SOT-563

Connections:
+3V3: C87.1, C88.1, C102.1, C103.1, R8.1, R9.1, R33.1, R35.1, R36.1, TP4.1, U30.1 (3V), U30.13 (3V), U32.3 (VDD), U33.3 (VCCA), U37.5 (V+), U38.4 (A0), U38.5 (V+); also elsewhere on the board
+5V: C96.1, D3.2 (A), TP5.1, U33.6 (OE), U33.7 (VCCB); also elsewhere on the board
+12V: M1.2 (+), M2.2 (+), M3.2 (+); also elsewhere on the board
/BM1370x4/RESET: U30.2 (GPIO1); also elsewhere on the board
/BM1370x4/RXD: U30.20 (GPIO18); also elsewhere on the board
/BM1370x4/TEMP_A0: U30.3 (GPIO2); also elsewhere on the board
/BM1370x4/TEMP_A1: U30.4 (GPIO3); also elsewhere on the board
/BM1370x4/TXD: U30.19 (GPIO17); also elsewhere on the board
/Power/LDO_EN: U30.8 (GPIO13); also elsewhere on the board
/Power/PWR_EN: U30.5 (GPIO10); also elsewhere on the board
/Power/VR_RDY: R36.2, U30.6 (GPIO11); also elsewhere on the board
/T-Display-S3/SCL: R8.2, U30.22 (GPIO43), U32.2 (SCL), U37.1 (SCL), U38.1 (SCL); also elsewhere on the board
/T-Display-S3/SDA: R9.2, U30.21 (GPIO44), U32.1 (SDA), U37.6 (SDA), U38.6 (SDA); also elsewhere on the board
/T-Display-S3/TACHO1: M1.3 (Tacho), R33.2, U32.6 (TACH1)
/T-Display-S3/TACHO2: M2.3 (Tacho), R35.2, U32.8 (TACH2)
GND: C87.2, C88.2, C96.2, C102.2, C103.2, M1.1 (-), M2.1 (-), M3.1 (-), U30.11 (GND), U30.14 (GND), U30.15 (GND), U30.23 (GND), U30.24 (GND), U32.4 (GND), U33.2 (GND), U37.2 (GND), U37.4 (A0), U38.2 (GND); also elsewhere on the board
unnamed: D3.1 (K), U30.12 (5V)
unnamed: M1.4 (PWM), U33.8 (B1Y)
unnamed: M2.4 (PWM), U33.1 (B2Y)
unnamed: U32.5 (PWM1), U33.5 (A1)
unnamed: U32.7 (PWM2), U33.4 (A2)

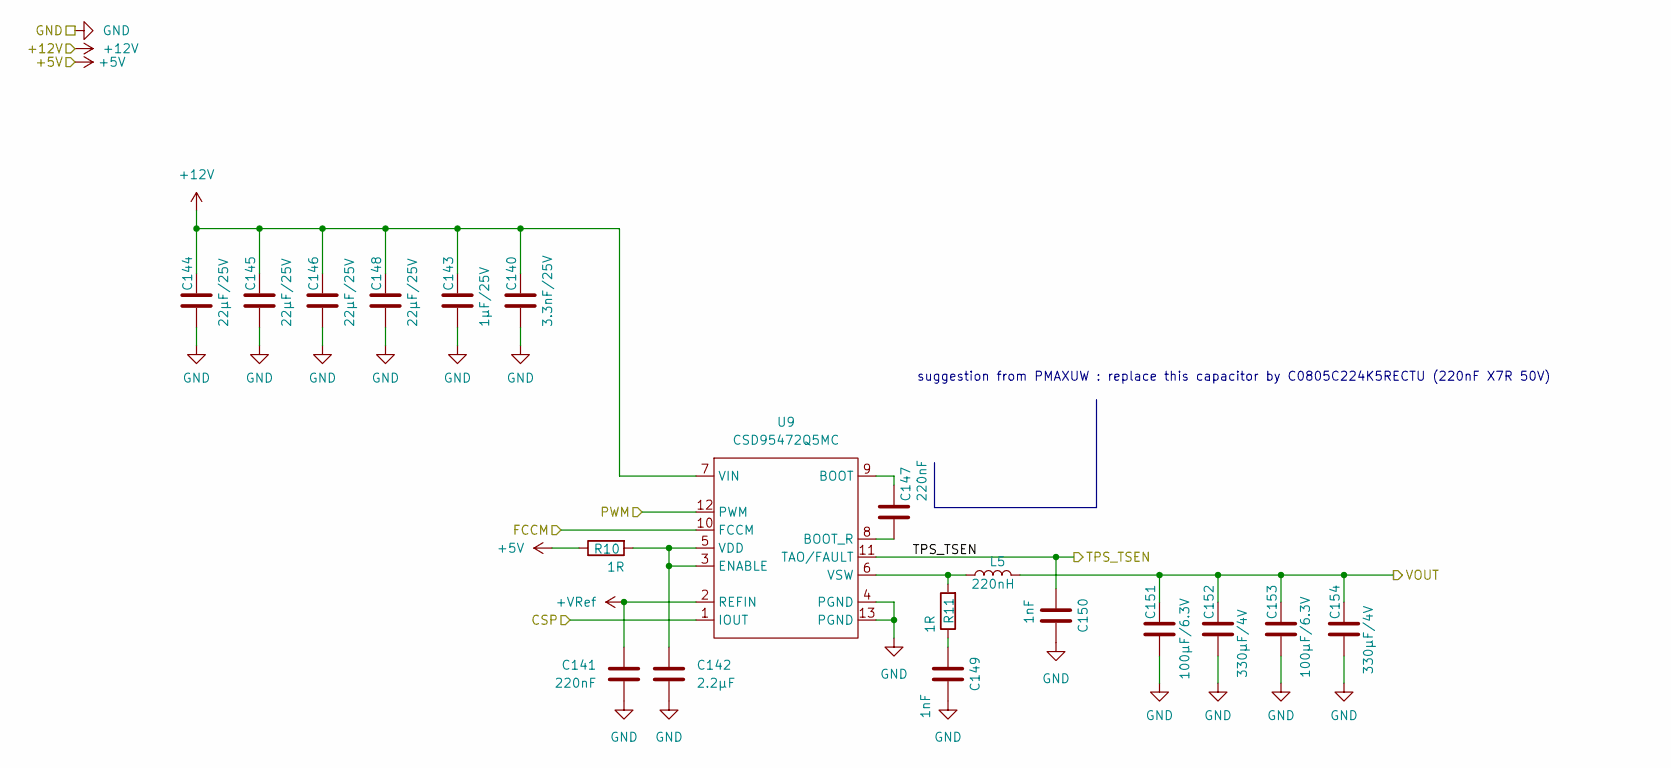
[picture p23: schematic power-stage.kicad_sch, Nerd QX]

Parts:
C140: 3.3nF/25V; C_0805_2012Metric
C141, C147: 220nF; C_0805_2012Metric
C142: 2.2µF; C_0805_2012Metric
C143: 1µF/25V; C_0805_2012Metric
C144, C145, C146, C148: 22µF/25V; C_1210_3225Metric
C149, C150: 1nF; C_0805_2012Metric
C151, C153: 100µF/6.3V; C_1210_3225Metric
C152, C154: 330µF/4V; C_1210_3225Metric
L5: 220nH; IFLR-4031GC-01-8x10
R10, R11: 1R; R_0805_2012Metric
U9: CSD95472Q5MC

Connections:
+5V: R10.1; also elsewhere on the board
+12V: C140.1, C143.1, C144.1, C145.1, C146.1, C148.1, U9.7 (VIN); also elsewhere on the board
+VRef: C141.1, U9.2 (REFIN); also elsewhere on the board
/Power/FCCM: U9.10 (FCCM); also elsewhere on the board
/Power/TPS_CSP2: U9.1 (IOUT); also elsewhere on the board
/Power/TPS_PWM2: U9.12 (PWM); also elsewhere on the board
/Power/TPS_TSEN: C150.1, U9.11 (TAO/FAULT); also elsewhere on the board
GND: C140.2, C141.2, C142.2, C143.2, C144.2, C145.2, C146.2, C148.2, C149.2, C150.2, C151.2, C152.2, C153.2, C154.2, U9.4 (PGND), U9.13 (PGND); also elsewhere on the board
unnamed: C149.1, R11.1
unnamed: C147.1, U9.9 (BOOT)
unnamed: C147.2, U9.8 (BOOT_R)
unnamed: C142.1, R10.2, U9.3 (ENABLE), U9.5 (VDD)
unnamed: L5.1, R11.2, U9.6 (VSW)
VDD: C151.1, C152.1, C153.1, C154.1, L5.2; also elsewhere on the board

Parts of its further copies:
C10, C14, C156, C162: 220nF; C_0805_2012Metric
C12, C157: 2.2µF; C_0805_2012Metric
C18, C109, C164, C165: 1nF; C_0805_2012Metric
C20, C23, C81, C89, C159, C160, C161, C163: 22µF/25V; C_1210_3225Metric
C21, C24, C166, C168: 100µF/6.3V; C_1210_3225Metric
C86, C90, C167, C169: 330µF/4V; C_1210_3225Metric
C117, C155: 3.3nF/25V; C_0805_2012Metric
C118, C158: 1µF/25V; C_0805_2012Metric
L1, L6: 220nH; IFLR-4031GC-01-8x10
R14, R15, R25, R27: 1R; R_0805_2012Metric
U4, U10: CSD95472Q5MC

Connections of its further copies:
+5V: R14.1, R25.1; also elsewhere on the board
+12V: C20.1, C23.1, C81.1, C89.1, C117.1, C118.1, C155.1, C158.1, C159.1, C160.1, C161.1, C163.1, U4.7 (VIN), U10.7 (VIN); also elsewhere on the board
+VRef: C10.1, C156.1, U4.2 (REFIN), U10.2 (REFIN); also elsewhere on the board
/Power/FCCM: U4.10 (FCCM), U10.10 (FCCM); also elsewhere on the board
/Power/TPS_CSP1: U4.1 (IOUT); also elsewhere on the board
/Power/TPS_CSP3: U10.1 (IOUT); also elsewhere on the board
/Power/TPS_PWM1: U4.12 (PWM); also elsewhere on the board
/Power/TPS_PWM3: U10.12 (PWM); also elsewhere on the board
/Power/TPS_TSEN: C109.1, C165.1, U4.11 (TAO/FAULT), U10.11 (TAO/FAULT); also elsewhere on the board
GND: C10.2, C12.2, C18.2, C20.2, C21.2, C23.2, C24.2, C81.2, C86.2, C89.2, C90.2, C109.2, C117.2, C118.2, C155.2, C156.2, C157.2, C158.2, C159.2, C160.2, C161.2, C163.2, C164.2, C165.2, C166.2, C167.2, C168.2, C169.2, U4.4 (PGND), U4.13 (PGND), U10.4 (PGND), U10.13 (PGND); also elsewhere on the board
unnamed: C18.1, R27.1
unnamed: C164.1, R15.1
unnamed: C14.1, U4.9 (BOOT)
unnamed: C14.2, U4.8 (BOOT_R)
unnamed: C12.1, R25.2, U4.3 (ENABLE), U4.5 (VDD)
unnamed: L1.1, R27.2, U4.6 (VSW)
unnamed: C162.1, U10.9 (BOOT)
unnamed: C162.2, U10.8 (BOOT_R)
unnamed: C157.1, R14.2, U10.3 (ENABLE), U10.5 (VDD)
unnamed: L6.1, R15.2, U10.6 (VSW)
VDD: C21.1, C24.1, C86.1, C90.1, C166.1, C167.1, C168.1, C169.1, L1.2, L6.2; also elsewhere on the board

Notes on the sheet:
suggestion from PMAXUW : replace this capacitor by C0805C224K5RECTU (220nF X7R 50V)

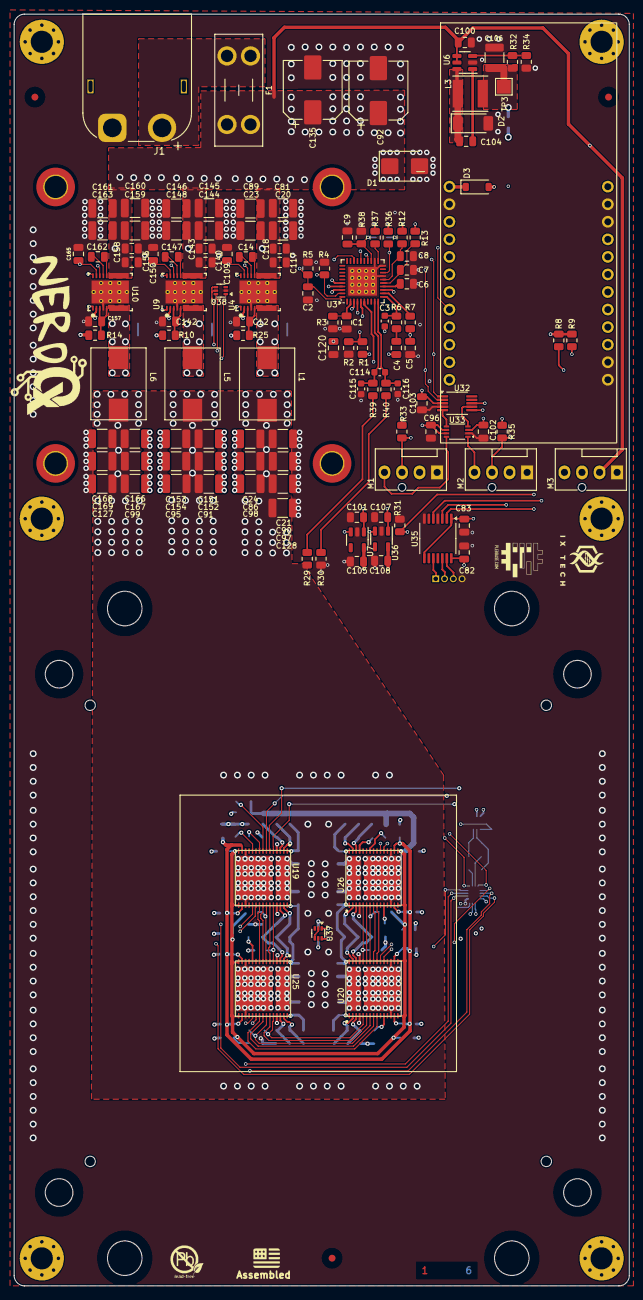
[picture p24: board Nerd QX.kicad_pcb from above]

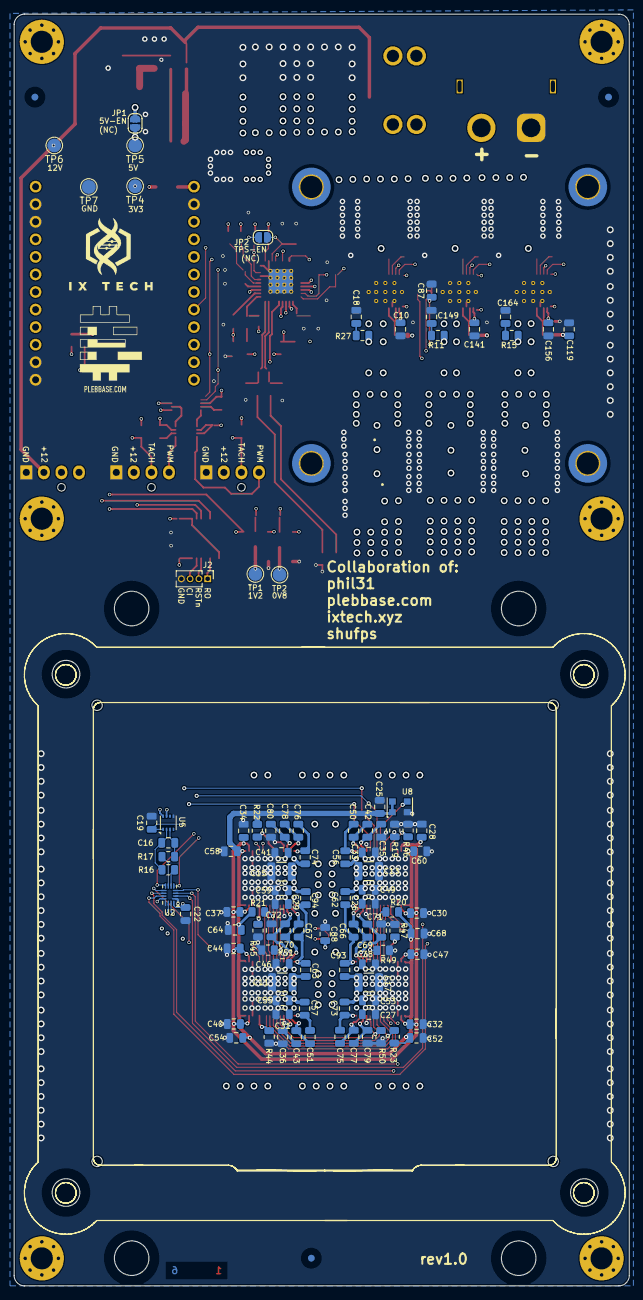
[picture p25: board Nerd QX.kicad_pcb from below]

Board: 6 copper layers, 89.0 x 184.0 mm, 237 parts (101 on the bottom side), 122 nets.

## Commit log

2025-09-06 Add STEP file for NerdQX
    [NerdQX.step]
2025-09-06 PCB dimensions plan added
2025-09-06 KiCad project data added for NerdQX
    ... The first revision of the NerdQX, following the successful testing of the first prototype. This basis provides the opportunity to manufacture the second prototype and thus later move into the pro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
    [DCJ250-20-B-XX-X_REVA1.step, FP1006V2-R.STEP, KMR231GLFS.stp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]
2025-09-06 Add gerbers files
    [Nerd QX-B_Cu.gbl, Nerd QX-B_Mask.gbs, Nerd QX-B_Paste.gbp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]
2025-09-06 Added bom for NerdQX
2025-10-01 silkscreen update for prototype boards
    [Nerd QX-B_Cu.gbl, Nerd QX-B_Mask.gbs, Nerd QX-B_Paste.gbp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]
2025-10-13 Latest lead photo inserted
2025-10-13 case sensitive
2025-10-13 Case sensitive CHANGELOG fix
2025-11-16 Updated schematics with correct cap rating
    We upgraded certain capacitors to a higher nF rating and have changed the schematic to reflect it so the BOM can be generated accurately.
    [Nerd QX.kicad_pcb, bm1370x4.kicad_sch, display.kicad_sch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]
2025-11-16 Gerber files exported and verified
    [Nerd QX-B_Cu.gbl, Nerd QX-B_Mask.gbs, Nerd QX-B_Paste.gbp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]
2025-11-16 BOM updated according to current schematics
